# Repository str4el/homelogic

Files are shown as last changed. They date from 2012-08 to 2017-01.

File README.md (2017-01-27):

Homelogic
---------

Die Homelogic ist eine dezentral arbeitende __SPS Steuerung__, die für den Hausgebrauch gedacht ist. Es gibt verschiedene Hardware die mit der selben Firmware laufen. Die meisten sind für den direktem betrieb am Netz ausgelegt und haben mehrere digitale Ein- und Ausgänge.

Das Projekt besteht aus den Plänen für die _Hardware_, der _Firmware_ darin, einer _Bibliothek_ und einen darauf aufbauendem _Steuerprogramm_.

Die Steuerung ist SPS typisch frei programmierbar, als Sprache kommt dafür eine Variante von _Anweisungsliste_ zum Einsatz.

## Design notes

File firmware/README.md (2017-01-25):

Firmware
========

Erstellen
---------

`make menuconfig` zeigt ein Auswahlmenü um die Firmwareoptionen
auszuwählen. Bei der ersten Ausführung werden die Standardeinstellungen
geladen. Es wird nun die Ausbaustufe ausgewählt.

Die Firmware wird mit `make` erstellt

`make distclean` löscht alle erzeugten Dateien inklusive der
Konfiguration.

Erstinstallation
----------------

Bei der USB Variante ist der Bootloader von Atmel vorinstalliert und
die Sicherheitsbits sind gesetzt, was ein Überschreiben durch __avrdude__
verhindert.
Da die Fuses für die Funktion der Firmware geändert werden müssen,
muss vorher ein _chiperase_ durchgeführt werden. Danach können mit
`make fuses` die Fuses richtig eingestellt werden.

Ist der __BOOTLOADER_SUPPORT__ aktiviert, muss der mitgelieferte
Bootloader von Atmel mit __avrdude__ installiert werden.

`make program` überträgt die Firmware.

Bei allen anderen Varianten reicht ein `make fuses program` aus.

Update
------

Um die Firmware von einer älteren Version zu aktualisieren reicht
ein `make program` aus.

Beispiel
--------

#### Erstinstallation USB-CPU mit Vollausstattung und Verwendung von AVR ISP MK2

`make distclean` wenn das Verzeichnis nicht sauber war.

`make menuconfig`

Nach der Auswahl `(CPU_USB) Target Hardware` müssen noch foglende optionen
gesetzt werden.

- `[*] I2C BUS --> [*] Real Time Clock`
- `[*] USB Support`
- `[*] Bootloader Support`

`make` erstellt die Firmware

Den Bootloader mit AVR ISP MK2 übertragen. Dabei wird ein _chiperase_ Ausgelöst.  
`avrdude -c avrispmkii -P usb -p at90usb1287 -U flash:w:at90usb128-bl-usb-1_0_1.hex:i`  
Der Bootloader ist nicht im Projekt enthalten kann aber von [Atmel](http://www.atmel.com/Images/megaUSB_DFU_Bootloaders.zip) bezogen werden.

`make fuses` um die setzt die Fusebits.

`make program` flasht die Firmware über den Bootloader per USB.

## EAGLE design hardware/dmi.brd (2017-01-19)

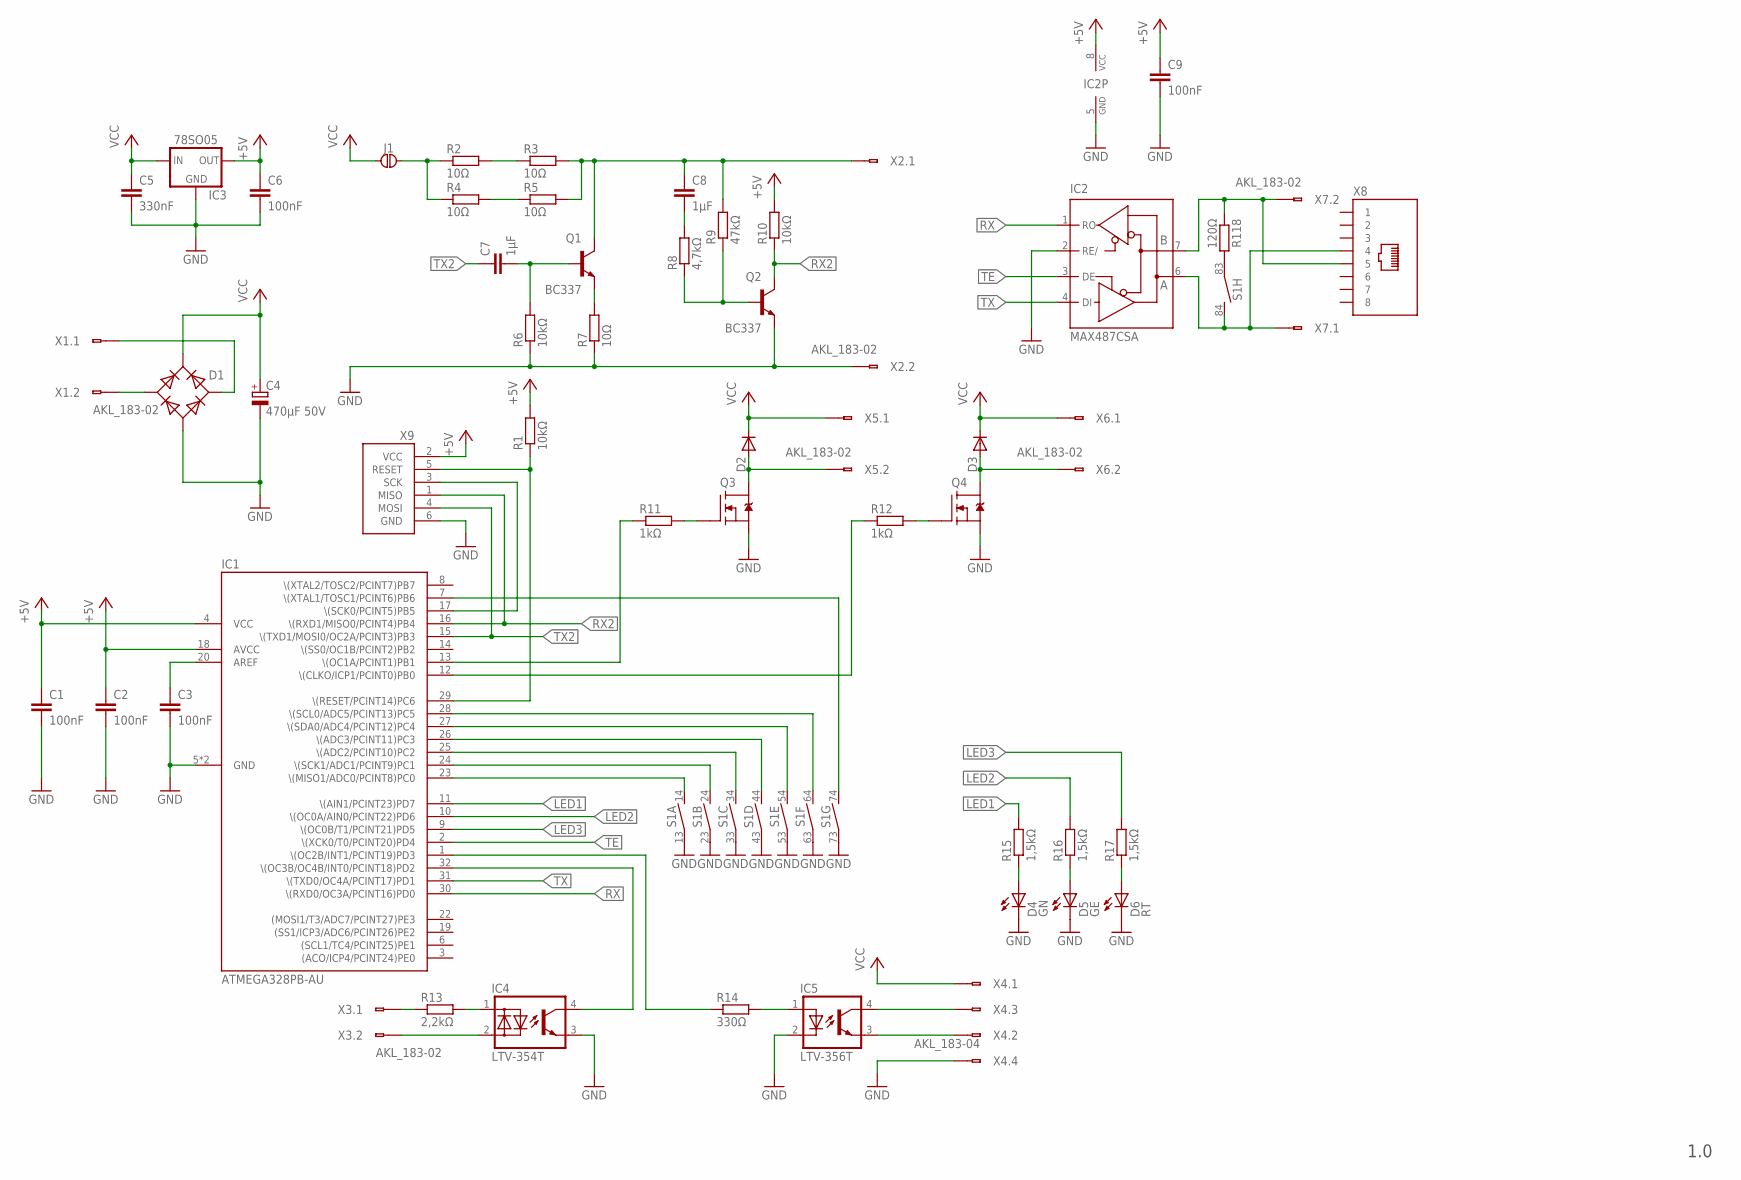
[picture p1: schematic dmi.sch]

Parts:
C1, C2, C3, C9: 100nF; CHIP_0603
C4: 470μF 50V; E5-13
C5: 330nF; CHIP_0805
C6: 100nF; CHIP_0805
C7, C8: 1μF; CHIP_1206
D1: GLEICHRICHTER-SDIP; SDIP04_508
D2, D3: DIODE-SOD123; SOD123
D4: GN; CHIP_0805
D5: GE; CHIP_0805
D6: RT; CHIP_0805
IC1: ATMEGA328PB-AU; QFP32_08
IC2: MAX487CSA; SOP08_127
IC3: 78SO05; SOP08_127
IC4: LTV-354T; SOP04_254
IC5: LTV-356T; SOP04_254
J1: JUMPER; JUMPER2
Q1, Q2: BC337; SOT23
Q3, Q4: N-MOS-SOT23-GSD; SOT23
R1, R6, R10: 10kΩ; CHIP_0603
R2, R3, R4, R5, R7: 10Ω; CHIP_1206
R8: 4,7kΩ; CHIP_0603
R9: 47kΩ; CHIP_0603
R11, R12: 1kΩ; CHIP_0603
R13: 2,2kΩ; CHIP_0603
R14: 330Ω; CHIP_0603
R15, R16, R17: 1,5kΩ; CHIP_0603
R118: 120Ω; CHIP_0805
S1: DP08D; DIP08_SMD
X1, X2, X3, X5, X6, X7: AKL_183-02
X4: AKL_183-04
X8: 8P8C; C-BMJ-0102
X9: ISP-AVR6; ML6

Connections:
+5V: C1.1, C2.1, C6.1, C9.1, IC1.4 (VCC), IC1.18 (AVCC), IC2.8 (VCC), IC3.1 (OUT), R1.2, R10.2, X9.2 (VCC)
GND: C1.2, C2.2, C3.2, C4.-, C5.2, C6.2, C9.2, D1.2 (-), D4.2 (C), D5.2 (C), D6.2 (C), IC1.5 (GND), IC1.21 (GND), IC2.2 (RE/), IC2.5 (GND), IC3.2 (GND), IC3.3 (GND), IC3.6 (GND), IC3.7 (GND), IC4.3 (E), IC5.2 (K), Q2.2 (E), Q3.2 (S), Q4.2 (S), R6.1, R7.1, S1.13 (3), S1.23 (3), S1.33 (3), S1.43 (3), S1.53 (3), S1.63 (3), S1.73 (3), X2.2, X4.4, X9.6 (GND)
LED1: IC1.11 (\(AIN1/PCINT23)PD7), R15.2
LED2: IC1.10 (\(OC0A/AIN0/PCINT22)PD6), R16.2
LED3: IC1.9 (\(OC0B/T1/PCINT21)PD5), R17.2
unnamed: IC1.32 (\(OC3B/OC4B/INT0/PCINT18)PD2), IC4.4 (C)
unnamed: IC4.2 (K), X3.2
unnamed: IC2.6 (A), S1.84 (4), X7.1, X8.P$4 (4)
unnamed: IC1.29 (\(RESET/PCINT14)PC6), R1.1, X9.5 (RESET)
unnamed: IC1.13 (\(OC1A/PCINT1)PB1), R11.1
unnamed: Q3.1 (G), R11.2
unnamed: D2.A, Q3.3 (D), X5.2
unnamed: IC5.3 (E), X4.2
unnamed: IC5.4 (C), X4.3
unnamed: IC1.1 (\(OC2B/INT1/PCINT19)PD3), R14.1
unnamed: IC5.1 (A), R14.2
unnamed: J1.P$2, R2.1, R4.1
unnamed: R2.2, R3.1
unnamed: R13.1, X3.1
unnamed: IC4.1 (A), R13.2
unnamed: Q1.2 (E), R7.2
unnamed: C7.2, Q1.1 (B), R6.2
unnamed: Q2.1 (B), R8.1, R9.1
unnamed: C8.2, R8.2
unnamed: D1.4 (AC2), X1.1
unnamed: C8.1, Q1.3 (C), R3.2, R5.2, R9.2, X2.1
unnamed: D1.3 (AC1), X1.2
unnamed: R4.2, R5.1
unnamed: Q4.1 (G), R12.2
unnamed: D3.A, Q4.3 (D), X6.2
unnamed: IC1.12 (\(CLKO/ICP1/PCINT0)PB0), R12.1
unnamed: IC2.7 (B), R118.1, X7.2, X8.P$5 (5)
unnamed: IC1.23 (\(MISO1/ADC0/PCINT8)PC0), S1.14 (4)
unnamed: IC1.24 (\(SCK1/ADC1/PCINT9)PC1), S1.24 (4)
unnamed: IC1.25 (\(ADC2/PCINT10)PC2), S1.34 (4)
unnamed: IC1.26 (\(ADC3/PCINT11)PC3), S1.44 (4)
unnamed: IC1.27 (\(SDA0/ADC4/PCINT12)PC4), S1.54 (4)
unnamed: R118.2, S1.83 (3)
unnamed: IC1.28 (\(SCL0/ADC5/PCINT13)PC5), S1.64 (4)
unnamed: IC1.7 (\(XTAL1/TOSC1/PCINT6)PB6), S1.74 (4)
unnamed: D6.1 (A), R17.1
unnamed: IC1.17 (\(SCK0/PCINT5)PB5), X9.3 (SCK)
unnamed: C3.1, IC1.20 (AREF)
unnamed: D4.1 (A), R15.1
unnamed: D5.1 (A), R16.1
RX: IC1.30 (\(RXD0/OC3A/PCINT16)PD0), IC2.1 (RO)
RX2: IC1.16 (\(RXD1/MISO0/PCINT4)PB4), Q2.3 (C), R10.1, X9.1 (MISO)
TE: IC1.2 (\(XCK0/T0/PCINT20)PD4), IC2.3 (DE)
TX: IC1.31 (\(TXD0/OC4A/PCINT17)PD1), IC2.4 (DI)
TX2: C7.1, IC1.15 (\(TXD1/MOSI0/OC2A/PCINT3)PB3), X9.4 (MOSI)
VCC: C4.+, C5.1, D1.1 (+), D2.K, D3.K, IC3.8 (IN), J1.P$1, X4.1, X5.1, X6.1

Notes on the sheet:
1.0

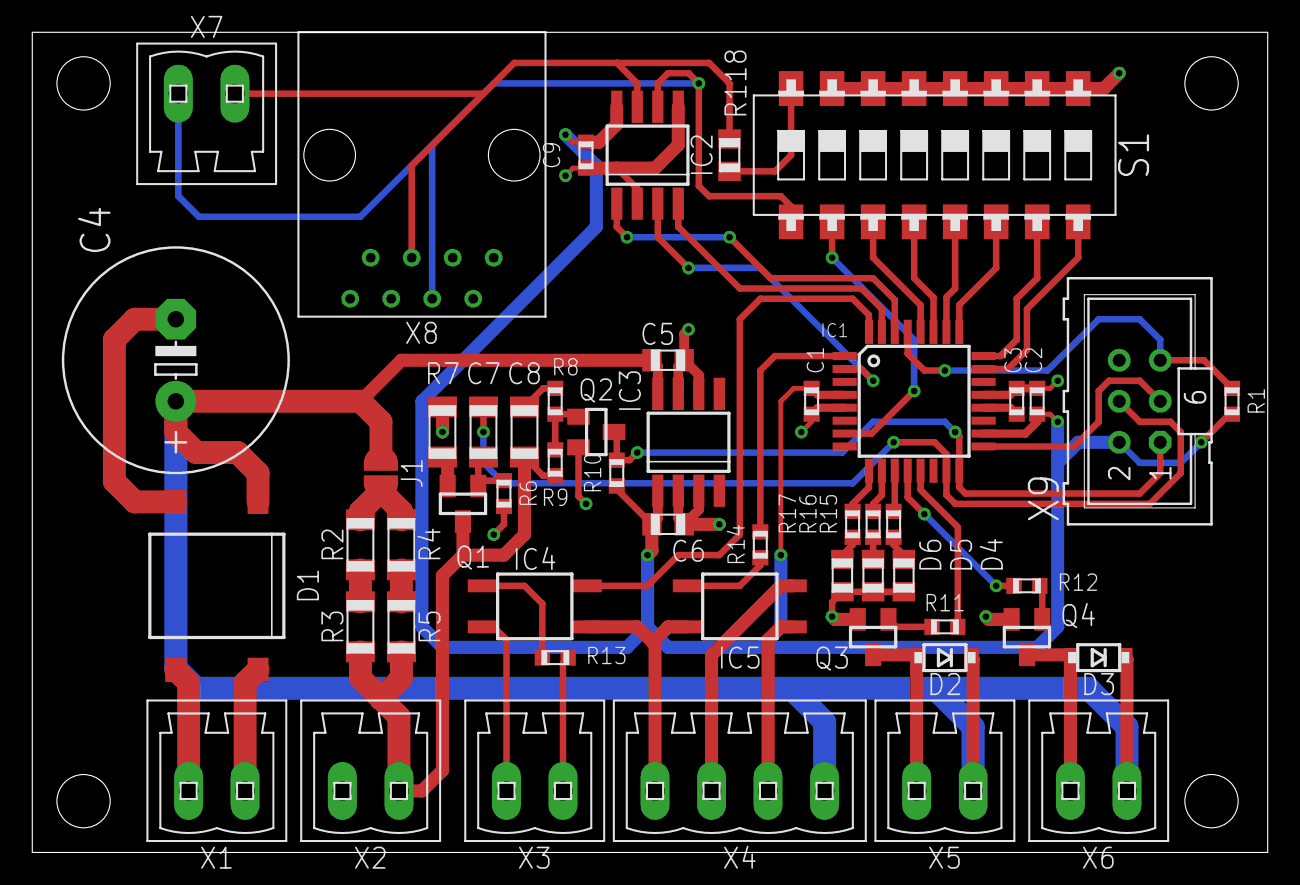
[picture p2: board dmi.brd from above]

Board: 2 copper layers, 76.5 x 50.8 mm, 53 parts (0 on the bottom side), 51 nets.

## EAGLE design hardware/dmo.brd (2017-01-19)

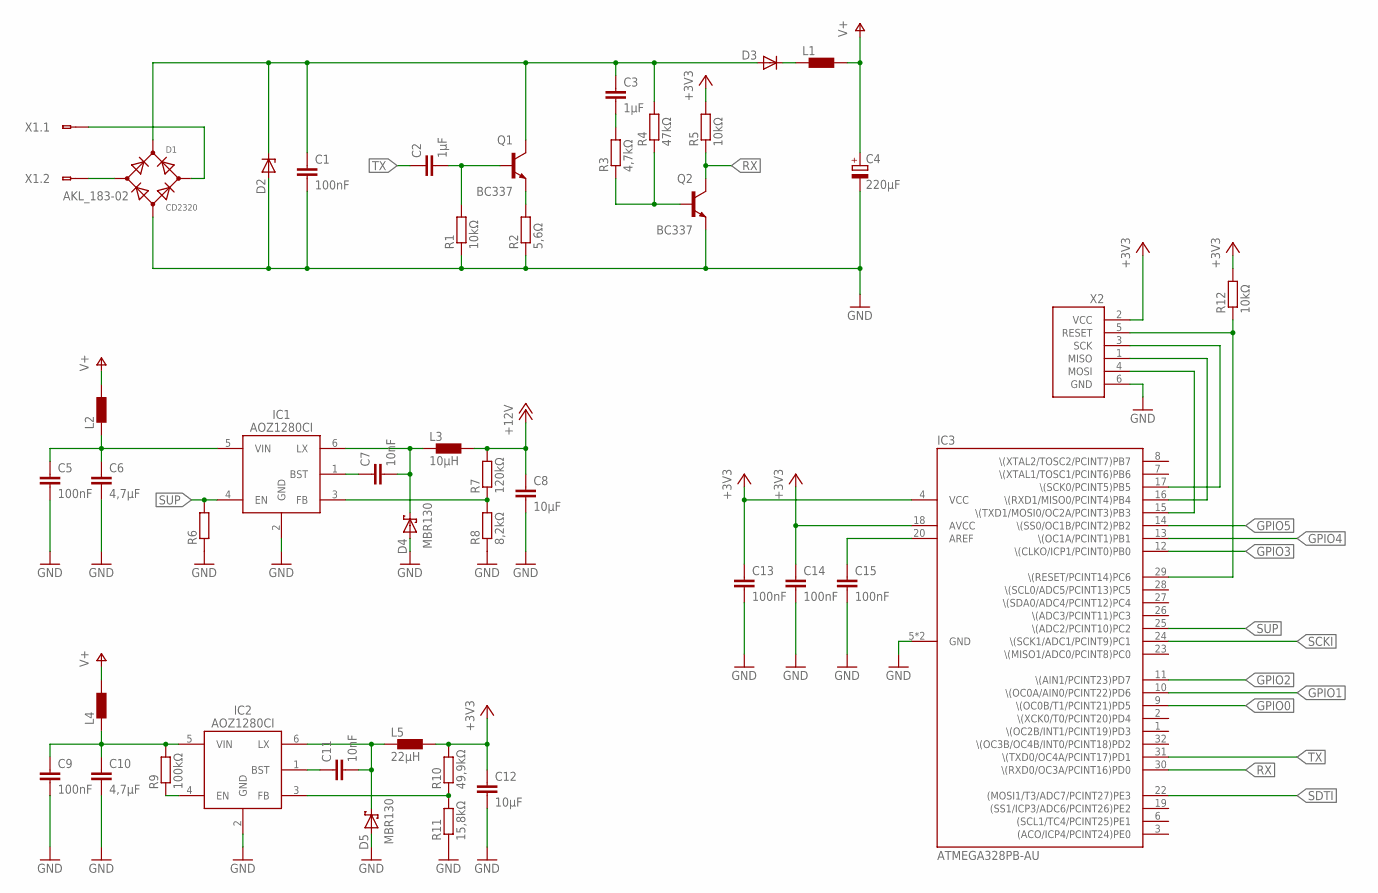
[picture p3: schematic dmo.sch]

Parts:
C1: 100nF; CHIP_1206
C2, C3: 1μF; CHIP_1206
C4: 220μF; E5-13
C5, C9: 100nF; CHIP_0805
C6, C10: 4,7μF; CHIP_1206
C7, C11: 10nF; CHIP_0603
C8, C12: 10μF; CHIP_1206
C13, C14, C15: 100nF; CHIP_0603
D1: CD2320; 2320
D2: Z-DIODE-SOD123; SOD123
D3: DIODE-SOD123; SOD123
D4, D5: MBR130; SOD123
IC1, IC2: AOZ1280CI; SOT23-6_095
IC3: ATMEGA328PB-AU; QFP32_08
L1, L2, L4: L_0805; CHIP_0805
L3: 10μH; CHIP_1210
L5: 22μH; CHIP_0805
Q1, Q2: BC337; SOT23
R1, R5, R12: 10kΩ; CHIP_0603
R2: 5,6Ω; CHIP_1206
R3: 4,7kΩ; CHIP_0603
R4: 47kΩ; CHIP_0603
R6: R_0603; CHIP_0603
R7: 120kΩ; CHIP_0603
R8: 8,2kΩ; CHIP_0603
R9: 100kΩ; CHIP_0603
R10: 49,9kΩ; CHIP_0603
R11: 15,8kΩ; CHIP_0603
X1: AKL_183-02
X2: ISP-AVR6; ML6

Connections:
+3V3: C12.1, C13.1, C14.1, IC3.4 (VCC), IC3.18 (AVCC), L5.1, R5.2, R10.2, R12.2, X2.2 (VCC)
+12V: C8.1, L3.1, R7.2
GND: C1.2, C4.-, C5.2, C6.2, C8.2, C9.2, C10.2, C12.2, C13.2, C14.2, C15.2, D1.-, D2.A, D4.A, D5.A, IC1.2 (GND), IC2.2 (GND), IC3.5 (GND), IC3.21 (GND), Q2.2 (E), R1.1, R2.1, R6.1, R8.1, R11.1, X2.6 (GND)
GPIO0: IC3.9 (\(OC0B/T1/PCINT21)PD5)
GPIO1: IC3.10 (\(OC0A/AIN0/PCINT22)PD6)
GPIO2: IC3.11 (\(AIN1/PCINT23)PD7)
GPIO3: IC3.12 (\(CLKO/ICP1/PCINT0)PB0)
GPIO4: IC3.13 (\(OC1A/PCINT1)PB1)
GPIO5: IC3.14 (\(SS0/OC1B/PCINT2)PB2)
unnamed: IC3.16 (\(RXD1/MISO0/PCINT4)PB4), X2.1 (MISO)
unnamed: IC3.15 (\(TXD1/MOSI0/OC2A/PCINT3)PB3), X2.4 (MOSI)
unnamed: D3.K, L1.2
unnamed: IC3.17 (\(SCK0/PCINT5)PB5), X2.3 (SCK)
unnamed: IC3.29 (\(RESET/PCINT14)PC6), R12.1, X2.5 (RESET)
unnamed: IC2.4 (EN), R9.1
unnamed: C11.1, IC2.1 (BST)
unnamed: C11.2, D5.K, IC2.6 (LX), L5.2
unnamed: IC2.3 (FB), R10.1, R11.2
unnamed: C9.1, C10.1, IC2.5 (VIN), L4.2, R9.2
unnamed: C7.1, IC1.1 (BST)
unnamed: C7.2, D4.K, IC1.6 (LX), L3.2
unnamed: IC1.3 (FB), R7.1, R8.2
unnamed: C5.1, C6.1, IC1.5 (VIN), L2.2
unnamed: C15.1, IC3.20 (AREF)
unnamed: Q1.2 (E), R2.2
unnamed: C2.2, Q1.1 (B), R1.2
unnamed: Q2.1 (B), R3.1, R4.1
unnamed: C3.2, R3.2
unnamed: D1.AC2, X1.1
unnamed: D1.AC1, X1.2
RX: IC3.30 (\(RXD0/OC3A/PCINT16)PD0), Q2.3 (C), R5.1
SCKI: IC3.24 (\(SCK1/ADC1/PCINT9)PC1)
SDTI: IC3.22 ((MOSI1/T3/ADC7/PCINT27)PE3)
SUP: IC1.4 (EN), IC3.25 (\(ADC2/PCINT10)PC2), R6.2
TX: C2.1, IC3.31 (\(TXD0/OC4A/PCINT17)PD1)
V+: C4.+, L1.1, L2.1, L4.1
VCC: C1.1, C3.1, D1.+, D2.K, D3.A, Q1.3 (C), R4.2

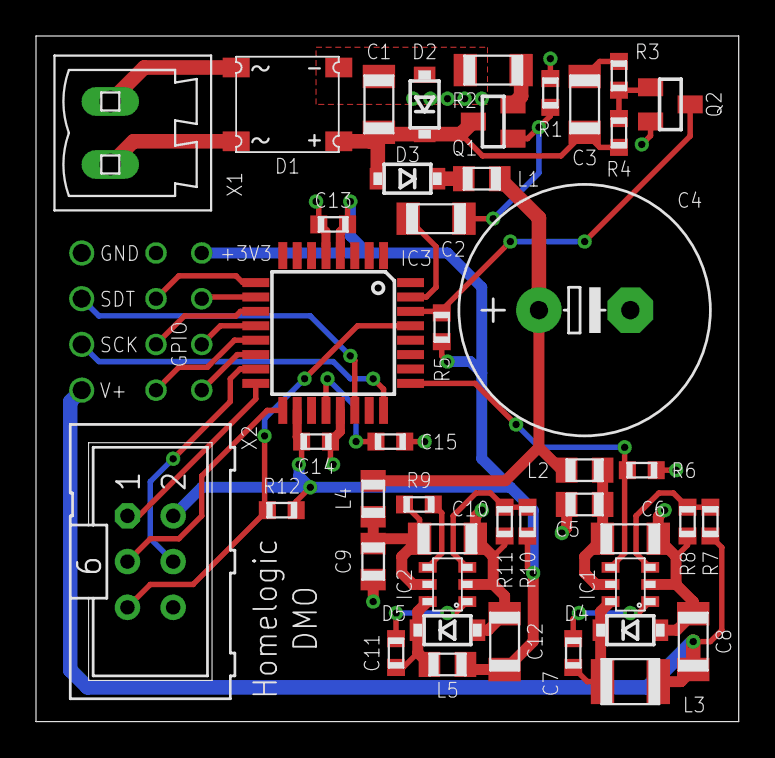
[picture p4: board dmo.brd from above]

Board: 2 copper layers, 39.0 x 38.1 mm, 44 parts (0 on the bottom side), 29 nets.

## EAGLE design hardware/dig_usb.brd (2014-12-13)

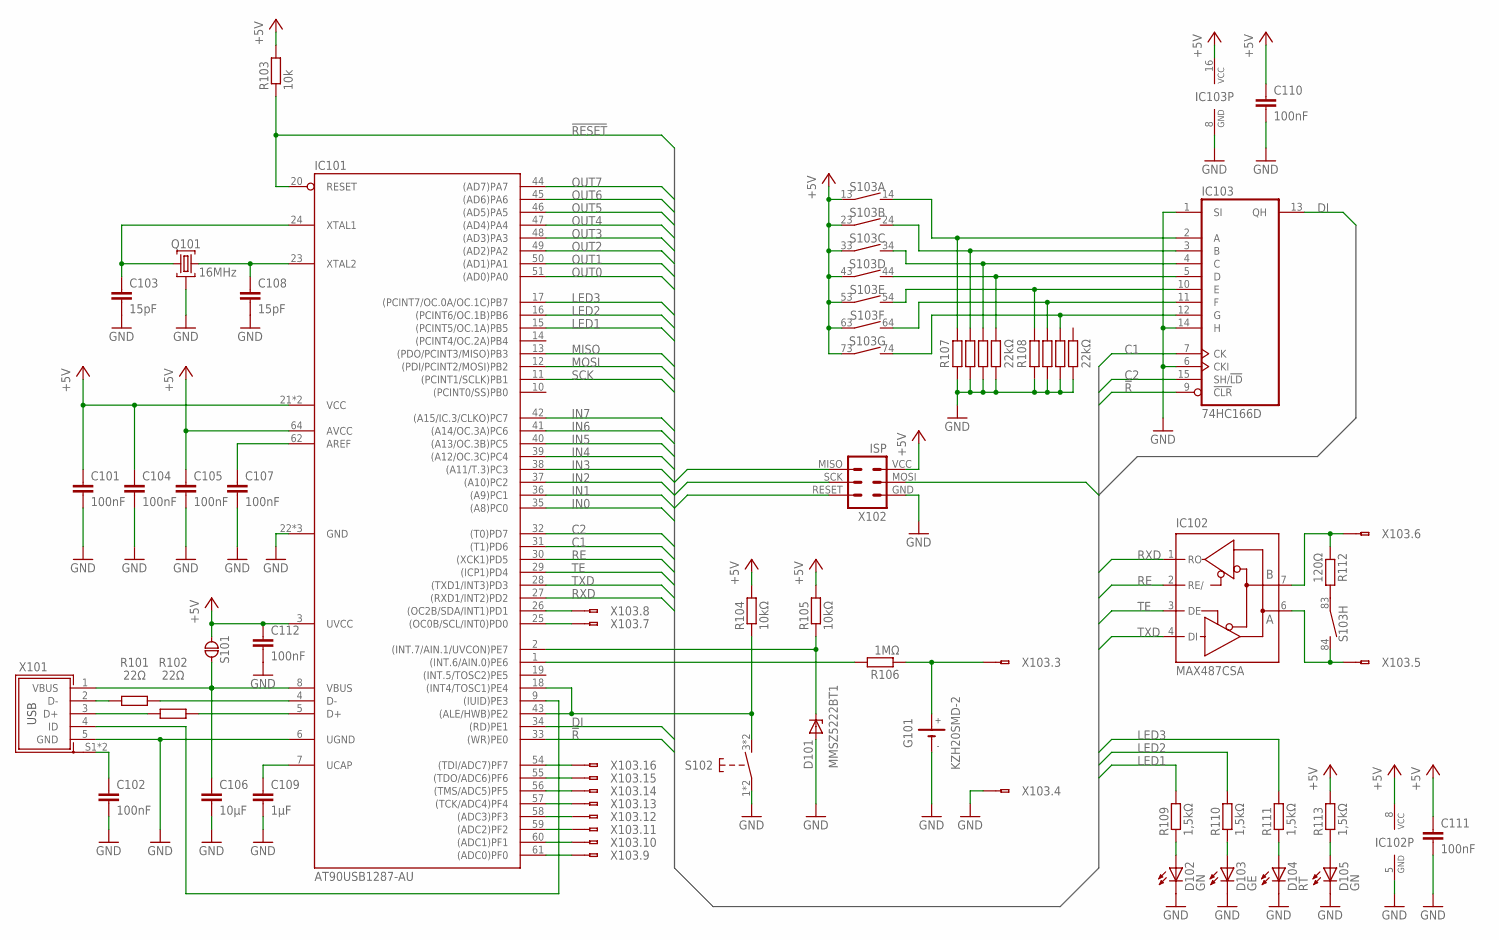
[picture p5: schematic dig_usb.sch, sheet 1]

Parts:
C101, C104, C105, C107, C110, C111, C112: 100nF; CHIP_0603
C102: 100nF; CHIP_0805
C103, C108: 15pF; CHIP_0805
C106: 10μF; CHIP_0805
C109: 1μF; CHIP_0805
D101: MMSZ5222BT1; SOD123
D102, D105: GN; CHIP_0805
D103: GE; CHIP_0805
D104: RT; CHIP_0805
G101: KZH20SMD-2; KHZ20SMD-2
IC101: AT90USB1287-AU; QFP64_08
IC102: MAX487CSA; SOP08_127
IC103: 74HC166D; SOP16_127
Q101: 16MHz; X22
R101, R102: 22Ω; CHIP_0805
R103: 10k; CHIP_0805
R104, R105: 10kΩ; CHIP_0805
R106: 1MΩ; CHIP_0805
R107, R108: 22kΩ; 1206
R109, R110, R111, R113: 1,5kΩ; CHIP_0805
R112: 120Ω; CHIP_0805
S101: JUMPER; JUMPER2
S102: KURZHUBS1; SCHURTER1301
S103: DP08D; DIP08_SMD
X101: USB-MINI-V; WE651005136421
X102: ISP; ML6
X103: WS34V

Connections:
!R: IC101.33 ((WR)PE0), IC103.9 (!CLR)
!RESET: IC101.20 (RESET), R103.1, X102.RESET
+5V: C101.1, C104.1, C105.1, C110.1, C111.1, C112.1, IC101.3 (UVCC), IC101.21 (VCC), IC101.52 (VCC), IC101.64 (AVCC), IC102.8 (VCC), IC103.16 (VCC), R103.2, R104.2, R105.2, R113.2, S101.P$1, S103.13 (3), S103.23 (3), S103.33 (3), S103.43 (3), S103.53 (3), S103.63 (3), S103.73 (3), X102.VCC; also elsewhere on the board
C1: IC101.31 ((T1)PD6), IC103.7 (CK)
C2: IC101.32 ((T0)PD7), IC103.15 (SH/!LD)
DI: IC101.34 ((RD)PE1), IC103.13 (QH)
GND: C101.2, C102.2, C103.2, C104.2, C105.2, C106.2, C107.2, C108.2, C109.2, C110.2, C111.2, C112.2, D101.A, D102.2 (C), D103.2 (C), D104.2 (C), D105.2 (C), G101.-, IC101.6 (UGND), IC101.22 (GND), IC101.53 (GND), IC101.63 (GND), IC102.5 (GND), IC103.1 (SI), IC103.6 (CKI), IC103.8 (GND), IC103.14 (H), Q101.2 (G), Q101.4 (G), R107.1A (1), R107.2A (3), R107.3A (5), R107.4A (7), R108.1A (1), R108.2A (3), R108.3A (5), R108.4A (7), S102.1, S102.2, X101.5 (GND), X102.GND, X103.4; also elsewhere on the board
IN0: IC101.35 ((A8)PC0); also elsewhere on the board
IN1: IC101.36 ((A9)PC1); also elsewhere on the board
IN2: IC101.37 ((A10)PC2); also elsewhere on the board
IN3: IC101.38 ((A11/T.3)PC3); also elsewhere on the board
IN4: IC101.39 ((A12/OC.3C)PC4); also elsewhere on the board
IN5: IC101.40 ((A13/OC.3B)PC5); also elsewhere on the board
IN6: IC101.41 ((A14/OC.3A)PC6); also elsewhere on the board
IN7: IC101.42 ((A15/IC.3/CLKO)PC7); also elsewhere on the board
LED1: IC101.15 ((PCINT5/OC.1A)PB5), R109.2
LED2: IC101.16 ((PCINT6/OC.1B)PB6), R110.2
LED3: IC101.17 ((PCINT7/OC.0A/OC.1C)PB7), R111.2
MISO: IC101.13 ((PDO/PCINT3/MISO)PB3), X102.MISO
MOSI: IC101.12 ((PDI/PCINT2/MOSI)PB2), X102.MOSI
unnamed: D104.1 (A), R111.1
unnamed: C107.1, IC101.62 (AREF)
unnamed: IC102.6 (A), S103.84 (4), X103.5
unnamed: IC101.1 ((INT.6/AIN.0)PE6), R106.2
unnamed: IC102.7 (B), R112.1, X103.6
unnamed: IC103.2 (A), R107.1B (2), S103.14 (4)
unnamed: IC103.3 (B), R107.2B (4), S103.24 (4)
unnamed: IC103.4 (C), R107.3B (6), S103.34 (4)
unnamed: IC103.5 (D), R107.4B (8), S103.44 (4)
unnamed: IC103.10 (E), R108.1B (2), S103.54 (4)
unnamed: IC103.11 (F), R108.2B (4), S103.64 (4)
unnamed: IC103.12 (G), R108.3B (6), S103.74 (4)
unnamed: R112.2, S103.83 (3)
unnamed: D105.1 (A), R113.1
unnamed: D102.1 (A), R109.1
unnamed: D103.1 (A), R110.1
unnamed: C109.1, IC101.7 (UCAP)
unnamed: R102.1, X101.3 (D+)
unnamed: IC101.5 (D+), R102.2
unnamed: R101.1, X101.2 (D-)
unnamed: IC101.4 (D-), R101.2
unnamed: IC101.9 ((IUID)PE3), X101.4 (ID)
unnamed: C106.1, IC101.8 (VBUS), S101.P$2, X101.1 (VBUS)
unnamed: C108.1, IC101.23 (XTAL2), Q101.3 (2)
unnamed: C103.1, IC101.24 (XTAL1), Q101.1
unnamed: D101.K, IC101.2 ((INT.7/AIN.1/UVCON)PE7), R105.1
unnamed: IC101.61 ((ADC0)PF0), X103.9
unnamed: IC101.60 ((ADC1)PF1), X103.10
unnamed: IC101.59 ((ADC2)PF2), X103.11
unnamed: IC101.58 ((ADC3)PF3), X103.12
unnamed: IC101.57 ((TCK/ADC4)PF4), X103.13
unnamed: IC101.56 ((TMS/ADC5)PF5), X103.14
unnamed: IC101.55 ((TDO/ADC6)PF6), X103.15
unnamed: IC101.54 ((TDI/ADC7)PF7), X103.16
unnamed: G101.+, R106.1, X103.3
unnamed: IC101.25 ((OC0B/SCL/INT0)PD0), X103.7
unnamed: IC101.26 ((OC2B/SDA/INT1)PD1), X103.8
unnamed: IC101.18 ((INT4/TOSC1)PE4), IC101.43 ((ALE/HWB)PE2), R104.1, S102.3 (S), S102.4 (S)
OUT0: IC101.51 ((AD0)PA0); also elsewhere on the board
OUT1: IC101.50 ((AD1)PA1); also elsewhere on the board
OUT2: IC101.49 ((AD2)PA2); also elsewhere on the board
OUT3: IC101.48 ((AD3)PA3); also elsewhere on the board
OUT4: IC101.47 ((AD4)PA4); also elsewhere on the board
OUT5: IC101.46 ((AD5)PA5); also elsewhere on the board
OUT6: IC101.45 ((AD6)PA6); also elsewhere on the board
OUT7: IC101.44 ((AD7)PA7); also elsewhere on the board
RE: IC101.30 ((XCK1)PD5), IC102.2 (RE/)
RXD: IC101.27 ((RXD1/INT2)PD2), IC102.1 (RO)
SCK: IC101.11 ((PCINT1/SCLK)PB1), X102.SCK
TE: IC101.29 ((ICP1)PD4), IC102.3 (DE)
TXD: IC101.28 ((TXD1/INT3)PD3), IC102.4 (DI)
USHIELD: C102.1, X101.S1 (SHIELD), X101.S2 (SHIELD)

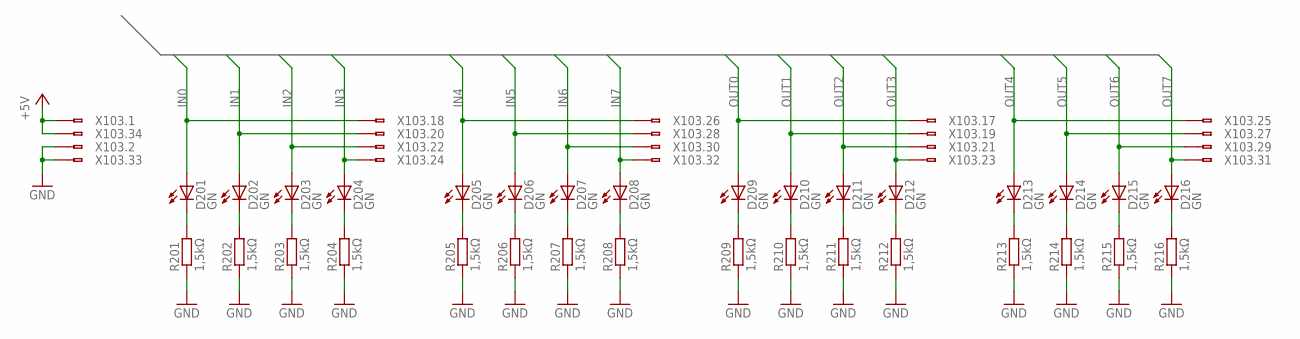
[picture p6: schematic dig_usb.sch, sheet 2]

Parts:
D201, D202, D203, D204, D205, D206, D207, D208, D209, D210, D211, D212, D213, D214, D215, D216: GN; CHIP_0805
R201, R202, R203, R204, R205, R206, R207, R208, R209, R210, R211, R212, R213, R214, R215, R216: 1,5kΩ; CHIP_0805
X103: WS34V

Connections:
+5V: X103.1, X103.34; also elsewhere on the board
GND: R201.1, R202.1, R203.1, R204.1, R205.1, R206.1, R207.1, R208.1, R209.1, R210.1, R211.1, R212.1, R213.1, R214.1, R215.1, R216.1, X103.2, X103.33; also elsewhere on the board
IN0: D201.1 (A), X103.18; also elsewhere on the board
IN1: D202.1 (A), X103.20; also elsewhere on the board
IN2: D203.1 (A), X103.22; also elsewhere on the board
IN3: D204.1 (A), X103.24; also elsewhere on the board
IN4: D205.1 (A), X103.26; also elsewhere on the board
IN5: D206.1 (A), X103.28; also elsewhere on the board
IN6: D207.1 (A), X103.30; also elsewhere on the board
IN7: D208.1 (A), X103.32; also elsewhere on the board
unnamed: D201.2 (C), R201.2
unnamed: D202.2 (C), R202.2
unnamed: D203.2 (C), R203.2
unnamed: D204.2 (C), R204.2
unnamed: D205.2 (C), R205.2
unnamed: D206.2 (C), R206.2
unnamed: D207.2 (C), R207.2
unnamed: D208.2 (C), R208.2
unnamed: D209.2 (C), R209.2
unnamed: D210.2 (C), R210.2
unnamed: D211.2 (C), R211.2
unnamed: D212.2 (C), R212.2
unnamed: D213.2 (C), R213.2
unnamed: D214.2 (C), R214.2
unnamed: D215.2 (C), R215.2
unnamed: D216.2 (C), R216.2
OUT0: D209.1 (A), X103.17; also elsewhere on the board
OUT1: D210.1 (A), X103.19; also elsewhere on the board
OUT2: D211.1 (A), X103.21; also elsewhere on the board
OUT3: D212.1 (A), X103.23; also elsewhere on the board
OUT4: D213.1 (A), X103.25; also elsewhere on the board
OUT5: D214.1 (A), X103.27; also elsewhere on the board
OUT6: D215.1 (A), X103.29; also elsewhere on the board
OUT7: D216.1 (A), X103.31; also elsewhere on the board

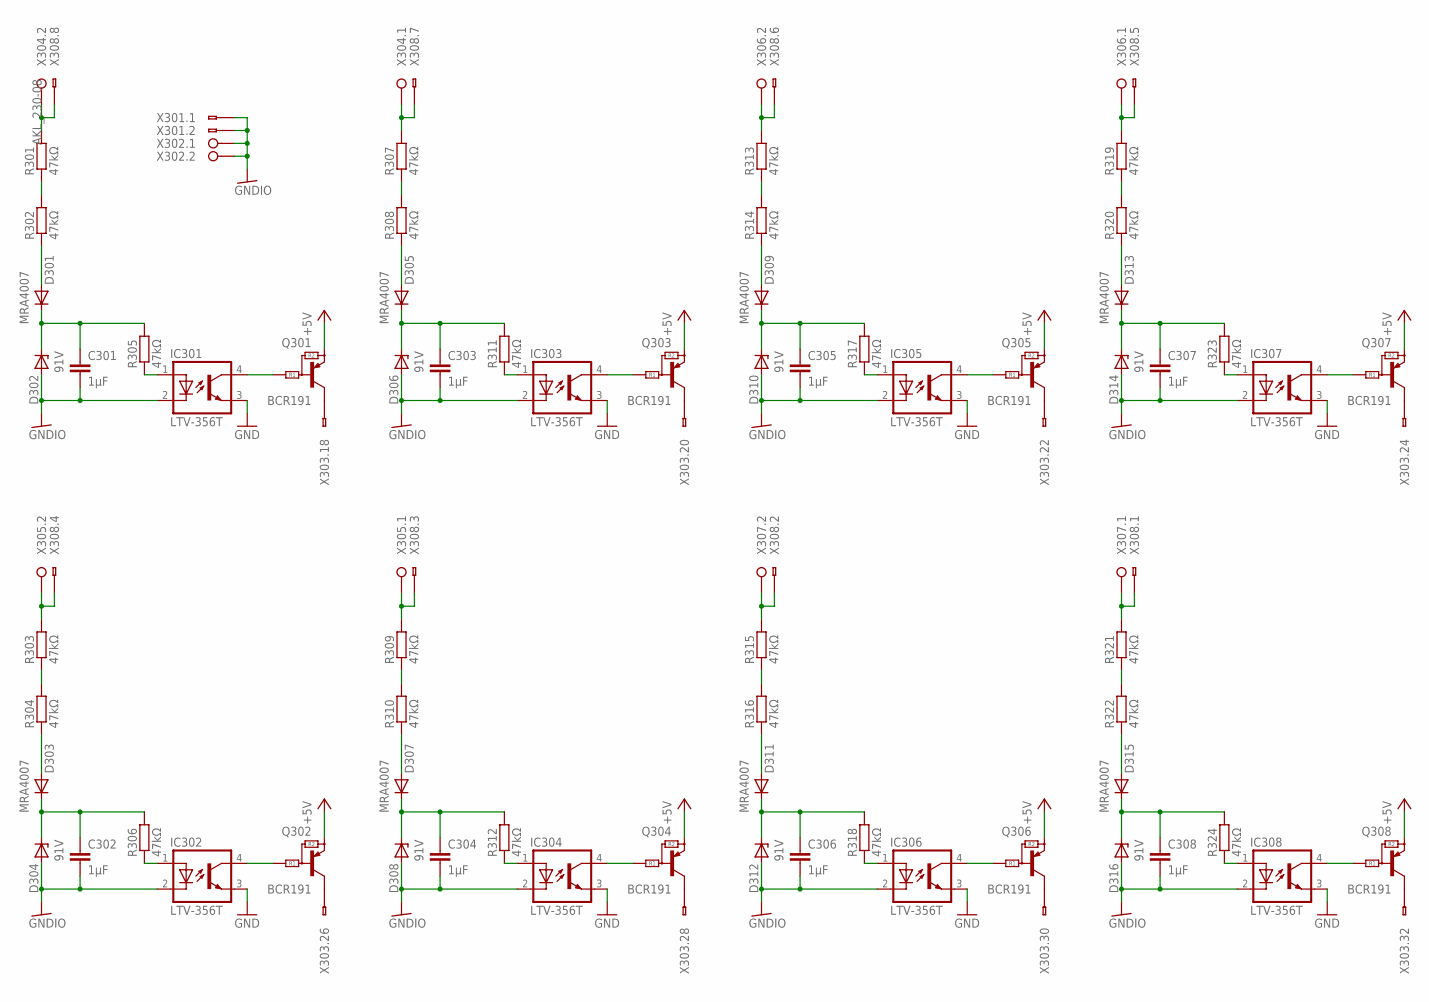
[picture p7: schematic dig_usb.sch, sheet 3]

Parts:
C301, C302, C303, C304, C305, C306, C307, C308: 1μF; CHIP_1206
D301, D303, D305, D307, D309, D311, D313, D315: MRA4007; DO214AC
D302, D304, D306, D308, D310, D312, D314, D316: 91V; SOD123
IC301, IC302, IC303, IC304, IC305, IC306, IC307, IC308: LTV-356T; SOP04_254
Q301, Q302, Q303, Q304, Q305, Q306, Q307, Q308: BCR191; SOT23
R301, R302, R303, R304, R305, R306, R307, R308, R309, R310, R311, R312, R313, R314, R315, R316, R317, R318, R319, R320, R321, R322, R323, R324: 47kΩ; CHIP_1206
X301: AKL_230-02
X302, X304, X305, X306, X307: RIA-73-02
X303: WS34V
X308: AKL_230-08

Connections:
+5V: Q301.2 (E), Q302.2 (E), Q303.2 (E), Q304.2 (E), Q305.2 (E), Q306.2 (E), Q307.2 (E), Q308.2 (E); also elsewhere on the board
GND: IC301.3 (E), IC302.3 (E), IC303.3 (E), IC304.3 (E), IC305.3 (E), IC306.3 (E), IC307.3 (E), IC308.3 (E); also elsewhere on the board
GNDIO: C301.2, C302.2, C303.2, C304.2, C305.2, C306.2, C307.2, C308.2, D302.A, D304.A, D306.A, D308.A, D310.A, D312.A, D314.A, D316.A, IC301.2 (K), IC302.2 (K), IC303.2 (K), IC304.2 (K), IC305.2 (K), IC306.2 (K), IC307.2 (K), IC308.2 (K), X301.P$1, X301.P$2, X302.1, X302.2; also elsewhere on the board
unnamed: R301.1, R302.2
unnamed: D301.A, R302.1
unnamed: C301.1, D301.K, D302.K, R305.2
unnamed: IC301.1 (A), R305.1
unnamed: D305.A, R308.1
unnamed: C303.1, D305.K, D306.K, R311.2
unnamed: IC303.1 (A), R311.1
unnamed: D309.A, R314.1
unnamed: C305.1, D309.K, D310.K, R317.2
unnamed: IC305.1 (A), R317.1
unnamed: D313.A, R320.1
unnamed: C307.1, D313.K, D314.K, R323.2
unnamed: R307.1, R308.2
unnamed: R313.1, R314.2
unnamed: IC307.1 (A), R323.1
unnamed: D303.A, R304.1
unnamed: C302.1, D303.K, D304.K, R306.2
unnamed: IC302.1 (A), R306.1
unnamed: D307.A, R310.1
unnamed: C304.1, D307.K, D308.K, R312.2
unnamed: R319.1, R320.2
unnamed: R307.2, X304.1, X308.P$7
unnamed: R301.2, X304.2, X308.P$8
unnamed: R319.2, X306.1, X308.P$5
unnamed: R313.2, X306.2, X308.P$6
unnamed: R303.1, R304.2
unnamed: R309.1, R310.2
unnamed: IC307.4 (C), Q307.1 (B)
unnamed: R315.1, R316.2
unnamed: R321.1, R322.2
unnamed: IC304.1 (A), R312.1
unnamed: R303.2, X305.2, X308.P$4
unnamed: D311.A, R316.1
unnamed: R309.2, X305.1, X308.P$3
unnamed: R321.2, X307.1, X308.P$1
unnamed: R315.2, X307.2, X308.P$2
unnamed: C306.1, D311.K, D312.K, R318.2
unnamed: IC306.1 (A), R318.1
unnamed: IC305.4 (C), Q305.1 (B)
unnamed: D315.A, R322.1
unnamed: IC303.4 (C), Q303.1 (B)
unnamed: IC301.4 (C), Q301.1 (B)
unnamed: C308.1, D315.K, D316.K, R324.2
unnamed: IC302.4 (C), Q302.1 (B)
unnamed: IC304.4 (C), Q304.1 (B)
unnamed: IC306.4 (C), Q306.1 (B)
unnamed: IC308.4 (C), Q308.1 (B)
unnamed: IC308.1 (A), R324.1
unnamed: Q301.3 (C), X303.18
unnamed: Q303.3 (C), X303.20
unnamed: Q305.3 (C), X303.22
unnamed: Q307.3 (C), X303.24
unnamed: Q302.3 (C), X303.26
unnamed: Q304.3 (C), X303.28
unnamed: Q306.3 (C), X303.30
unnamed: Q308.3 (C), X303.32

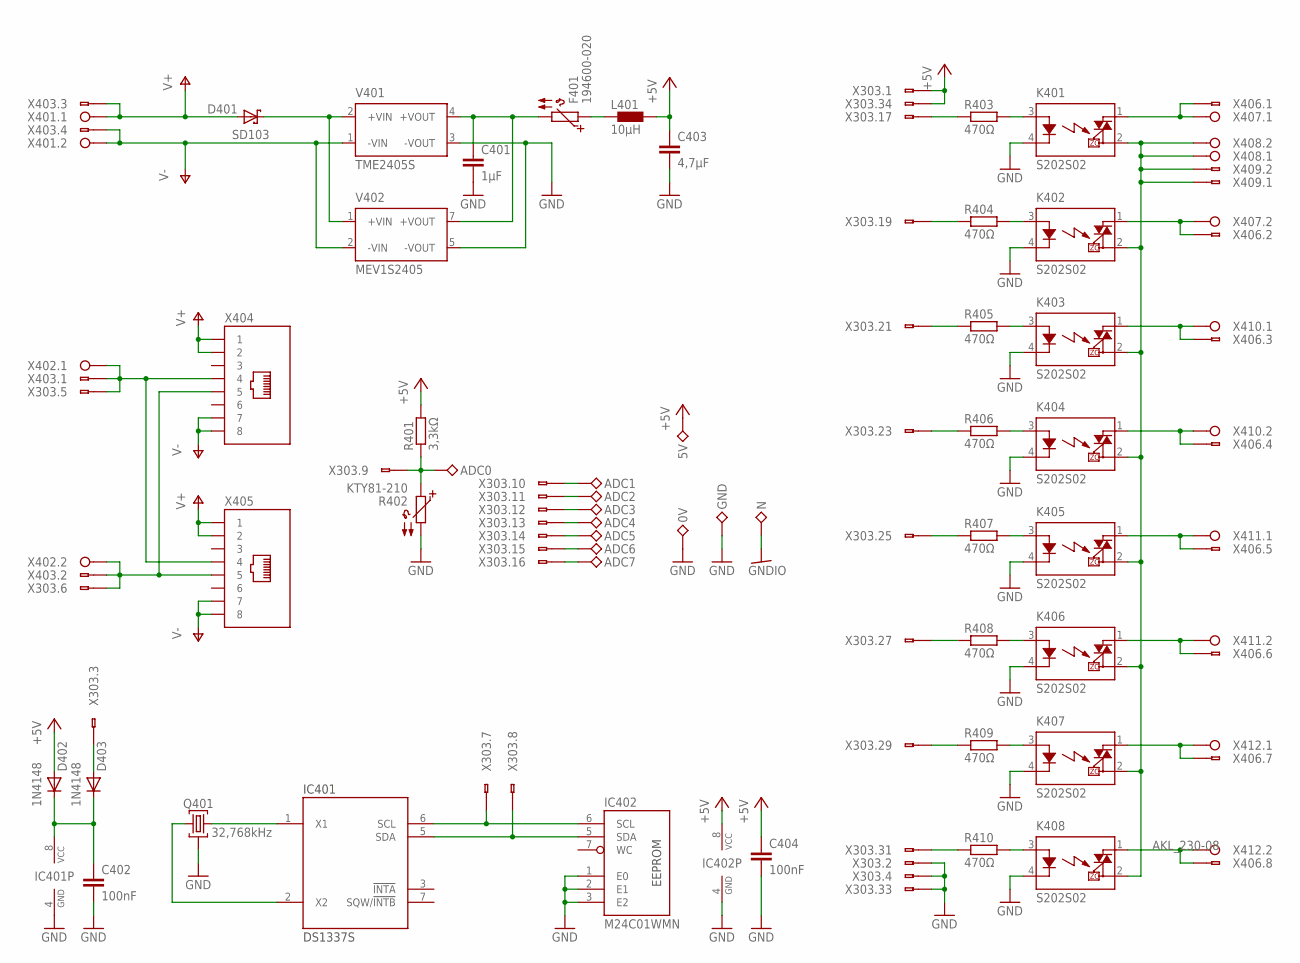
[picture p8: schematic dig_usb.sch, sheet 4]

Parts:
0V, 5V: TEST_VIA_08; VIA08
ADC0, ADC1, ADC2, ADC3, ADC4, ADC5, ADC6, ADC7: TEST_PAD_SMALL; PADS
C401: 1μF; CHIP_0805
C402, C404: 100nF; CHIP_0603
C403: 4,7μF; CHIP_0805
D401: SD103; SOD123
D402, D403: 1N4148; SOD123
F401: 194600-020; CHIP_1812
GND: TEST_VIA_08; VIA08
IC401: DS1337S; SOP08_127
IC402: M24C01WMN; SOP08_127
K401, K402, K403, K404, K405, K406, K407, K408: S202S02; SIP4
L401: 10μH; 1812AF
N: TEST_VIA_08; VIA08
Q401: 32,768kHz; MS1V-T1K
R401: 3,3kΩ; CHIP_0805
R402: KTY81-210; TO92
R403, R404, R405, R406, R407, R408, R409, R410: 470Ω; CHIP_0805
V401: TME2405S; TME-24V; MPN TME 2405S
V402: MEV1S2405; MEV1S
X303: WS34V
X401, X402, X407, X408, X410, X411, X412: RIA-73-02
X403: AKL_230-04
X404, X405: 8P8C; C-BMJ-0102
X406: AKL_230-08
X409: AKL_230-02

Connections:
+5V: 5V.1, C403.1, C404.1, D402.A, IC402.8 (VCC), L401.1, R401.2, X303.1, X303.34; also elsewhere on the board
GND: 0V.1, C401.2, C402.2, C403.2, C404.2, GND.1, IC401.4 (GND), IC402.1 (E0), IC402.2 (E1), IC402.3 (E2), IC402.4 (GND), K401.4 (K), K402.4 (K), K403.4 (K), K404.4 (K), K405.4 (K), K406.4 (K), K407.4 (K), K408.4 (K), Q401.G, R402.2, V401.3 (-VOUT), V402.5 (-VOUT), X303.2, X303.4, X303.33; also elsewhere on the board
GNDIO: N.1; also elsewhere on the board
L: K401.2 (DS2), K402.2 (DS2), K403.2 (DS2), K404.2 (DS2), K405.2 (DS2), K406.2 (DS2), K407.2 (DS2), K408.2 (DS2), X408.1, X408.2, X409.P$1, X409.P$2
unnamed: K401.3 (A), R403.2
unnamed: K402.3 (A), R404.2
unnamed: C401.1, F401.2, V401.4 (+VOUT), V402.7 (+VOUT)
unnamed: D401.K, V401.2 (+VIN), V402.1 (+VIN)
unnamed: F401.1, L401.2
unnamed: K403.3 (A), R405.2
unnamed: K404.3 (A), R406.2
unnamed: ADC1.1, X303.10
unnamed: K405.3 (A), R407.2
unnamed: K406.3 (A), R408.2
unnamed: K407.3 (A), R409.2
unnamed: C402.1, D402.K, D403.K, IC401.8 (VCC)
unnamed: K408.3 (A), R410.2
unnamed: R403.1, X303.17
unnamed: K401.1 (DS1), X406.P$1, X407.1
unnamed: K402.1 (DS1), X406.P$2, X407.2
unnamed: K403.1 (DS1), X406.P$3, X410.1
unnamed: K404.1 (DS1), X406.P$4, X410.2
unnamed: K405.1 (DS1), X406.P$5, X411.1
unnamed: R404.1, X303.19
unnamed: K406.1 (DS1), X406.P$6, X411.2
unnamed: K407.1 (DS1), X406.P$7, X412.1
unnamed: R405.1, X303.21
unnamed: R406.1, X303.23
unnamed: K408.1 (DS1), X406.P$8, X412.2
unnamed: R407.1, X303.25
unnamed: R408.1, X303.27
unnamed: R409.1, X303.29
unnamed: R410.1, X303.31
unnamed: IC401.1 (X1), Q401.2
unnamed: IC401.2 (X2), Q401.1
unnamed: D403.A, X303.3
unnamed: IC401.6 (SCL), IC402.6 (SCL), X303.7
unnamed: IC401.5 (SDA), IC402.5 (SDA), X303.8
unnamed: X303.6, X402.2, X403.P$2, X404.P$5 (5), X405.P$5 (5)
unnamed: X303.5, X402.1, X403.P$1, X404.P$4 (4), X405.P$4 (4)
unnamed: ADC0.1, R401.1, R402.1, X303.9
unnamed: ADC2.1, X303.11
unnamed: ADC3.1, X303.12
unnamed: ADC4.1, X303.13
unnamed: ADC5.1, X303.14
unnamed: ADC6.1, X303.15
unnamed: ADC7.1, X303.16
V+: D401.A, X401.1, X403.P$3, X404.P$1 (1), X404.P$2 (2), X405.P$1 (1), X405.P$2 (2)
V-: V401.1 (-VIN), V402.2 (-VIN), X401.2, X403.P$4, X404.P$7 (7), X404.P$8 (8), X405.P$7 (7), X405.P$8 (8)

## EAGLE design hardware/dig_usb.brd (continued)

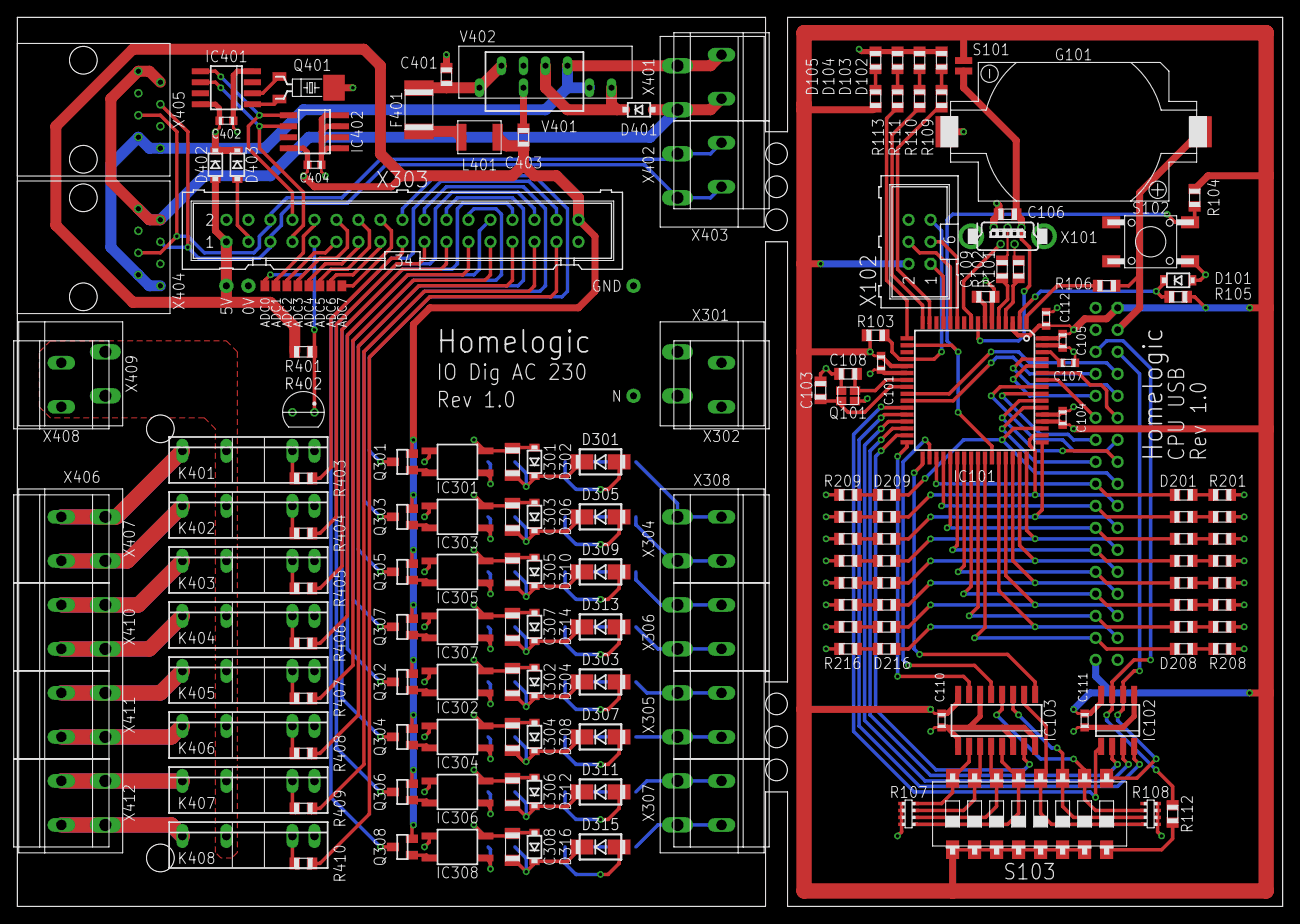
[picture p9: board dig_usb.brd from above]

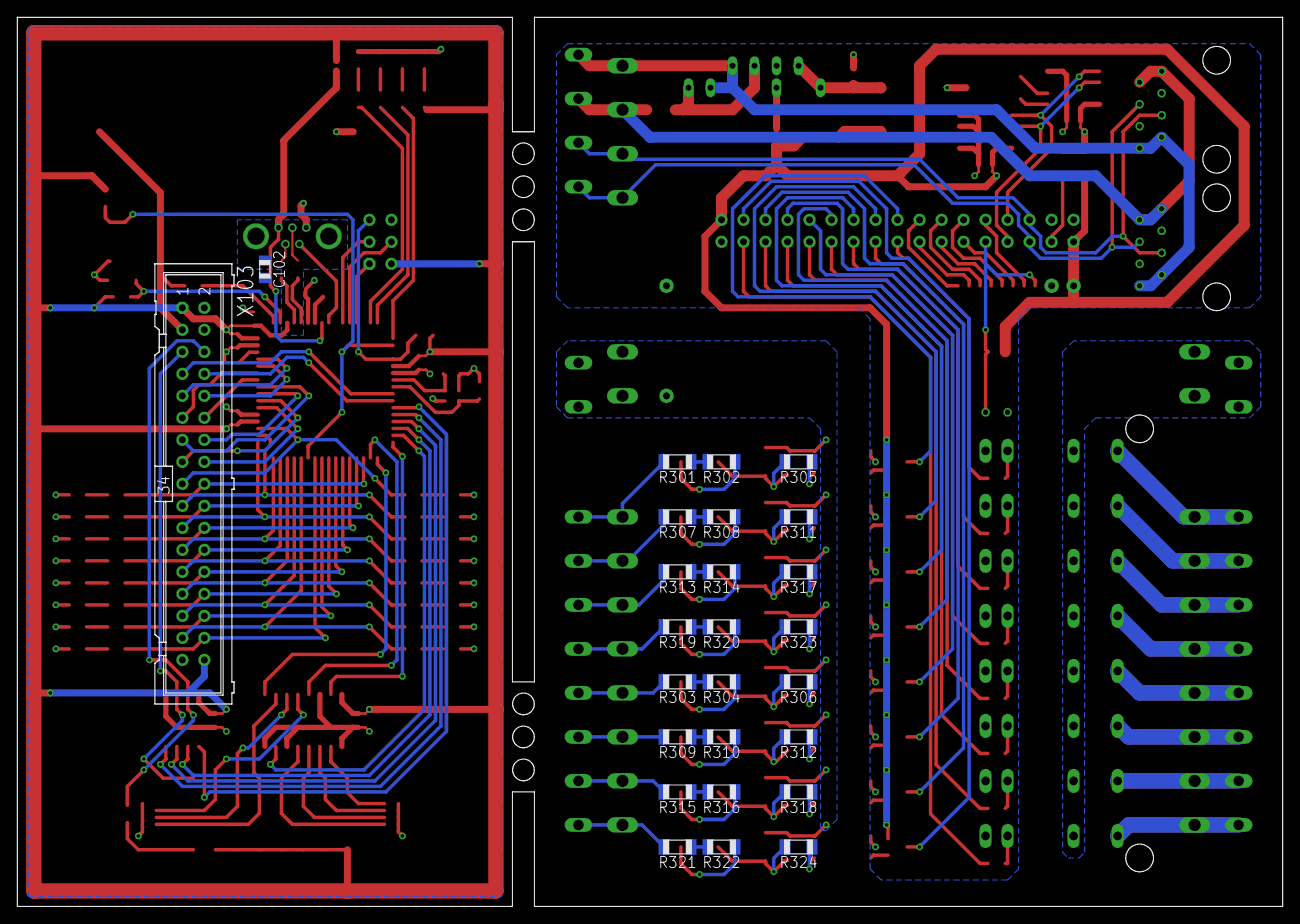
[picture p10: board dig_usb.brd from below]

Board: 2 copper layers, 146.1 x 102.6 mm, 201 parts (26 on the bottom side), 191 nets.

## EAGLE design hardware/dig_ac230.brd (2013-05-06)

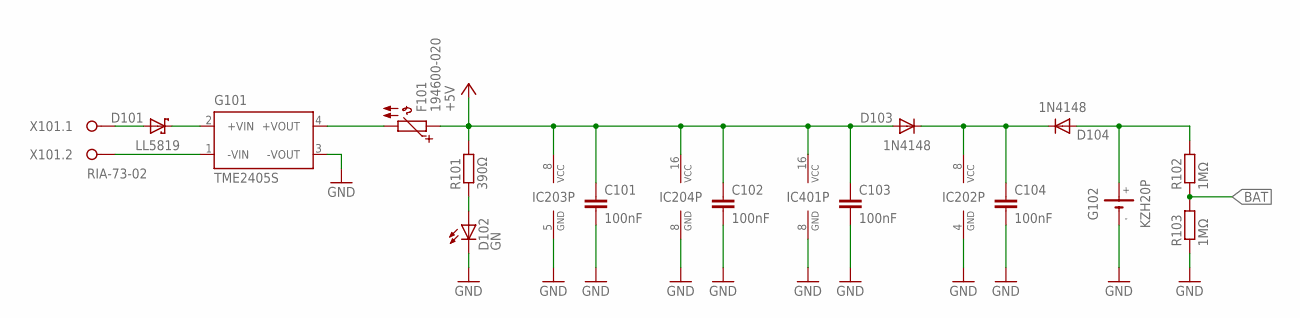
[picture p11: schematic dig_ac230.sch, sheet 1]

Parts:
C101, C102, C103, C104: 100nF; CHIP_0805
D101: LL5819; MELF
D102: GN; LED3MM
D103, D104: 1N4148; MINIMELF
F101: 194600-020; CHIP_1812
G101: TME2405S; TME-24V; MPN TME 2405S
G102: KZH20P
IC202: DS1337S; SOP08_127
IC203: MAX487CSA; SOP08_127
IC204: 74HC166D; SOP16_127
IC401: 74HC595D; SOP16_127
R101: 390Ω; CHIP_0805
R102, R103: 1MΩ; CHIP_0805
X101: RIA-73-02

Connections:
+5V: C101.1, C102.1, C103.1, D103.A, F101.1, IC203.8 (VCC), IC204.16 (VCC), IC401.16 (VCC), R101.2; also elsewhere on the board
BAT: R102.1, R103.2; also elsewhere on the board
GND: C101.2, C102.2, C103.2, C104.2, D102.K (C), G101.3 (-VOUT), G102.N (-), IC202.4 (GND), IC203.5 (GND), IC204.8 (GND), IC401.8 (GND), R103.1; also elsewhere on the board
unnamed: G101.1 (-VIN), X101.2
unnamed: D104.A, G102.P1 (+), G102.P2 (+), R102.2
unnamed: D101.K, G101.2 (+VIN)
unnamed: D101.A, X101.1
unnamed: F101.2, G101.4 (+VOUT)
unnamed: D102.A, R101.1
unnamed: C104.1, D103.K, D104.K, IC202.8 (VCC)

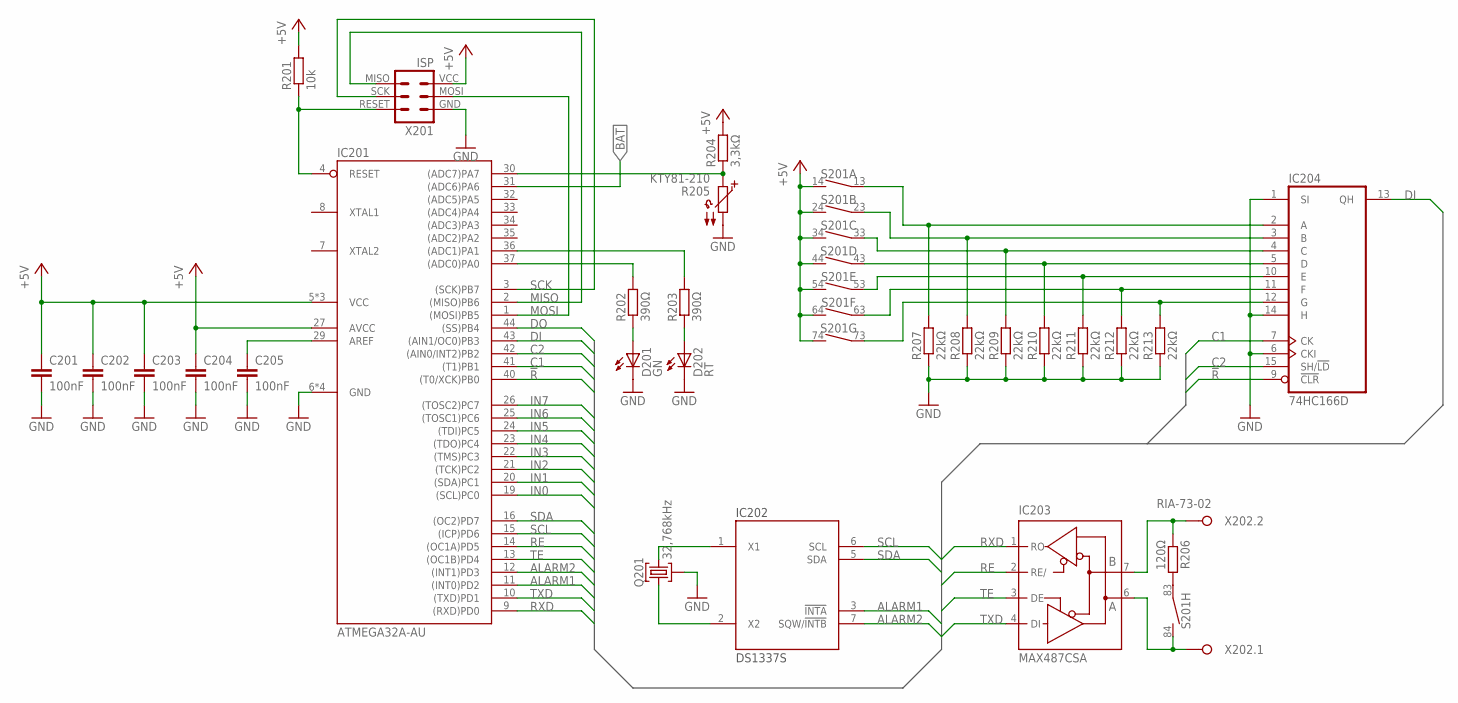
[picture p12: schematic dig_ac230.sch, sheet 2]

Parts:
C201, C202, C203, C204, C205: 100nF; CHIP_0805
D201: GN; LED3MM
D202: RT; LED3MM
IC201: ATMEGA32A-AU; QFP44_08
IC202: DS1337S; SOP08_127
IC203: MAX487CSA; SOP08_127
IC204: 74HC166D; SOP16_127
Q201: 32,768kHz; MS1V-T1K
R201: 10k; CHIP_0805
R202, R203: 390Ω; CHIP_0805
R204: 3,3kΩ; CHIP_0805
R205: KTY81-210; TO92
R206: 120Ω; CHIP_0805
R207, R208, R209, R210, R211, R212, R213: 22kΩ; CHIP_0805
S201: DP08
X201: ISP; ML6L
X202: RIA-73-02

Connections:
!R: IC201.40 ((T0/XCK)PB0), IC204.9 (!CLR); also elsewhere on the board
+5V: C201.1, C202.1, C203.1, C204.1, IC201.5 (VCC), IC201.17 (VCC), IC201.27 (AVCC), IC201.38 (VCC), R201.2, R204.2, S201.14 (4), S201.24 (4), S201.34 (4), S201.44 (4), S201.54 (4), S201.64 (4), S201.74 (4), X201.VCC; also elsewhere on the board
ALARM1: IC201.11 ((INT0)PD2), IC202.3 (!INTA)
ALARM2: IC201.12 ((INT1)PD3), IC202.7 (SQW/!INTB)
BAT: IC201.31 ((ADC6)PA6); also elsewhere on the board
C1: IC201.41 ((T1)PB1), IC204.7 (CK); also elsewhere on the board
C2: IC201.42 ((AIN0/INT2)PB2), IC204.15 (SH/!LD); also elsewhere on the board
DI: IC201.43 ((AIN1/OC0)PB3), IC204.13 (QH)
DO: IC201.44 ((SS)PB4); also elsewhere on the board
GND: C201.2, C202.2, C203.2, C204.2, C205.2, D201.K (C), D202.K (C), IC201.6 (GND), IC201.18 (GND), IC201.28 (GND), IC201.39 (GND), IC204.1 (SI), IC204.6 (CKI), IC204.14 (H), Q201.G, R205.2, R207.1, R208.1, R209.1, R210.1, R211.1, R212.1, R213.1, X201.GND; also elsewhere on the board
IN0: IC201.19 ((SCL)PC0); also elsewhere on the board
IN1: IC201.20 ((SDA)PC1); also elsewhere on the board
IN2: IC201.21 ((TCK)PC2); also elsewhere on the board
IN3: IC201.22 ((TMS)PC3); also elsewhere on the board
IN4: IC201.23 ((TDO)PC4); also elsewhere on the board
IN5: IC201.24 ((TDI)PC5); also elsewhere on the board
IN6: IC201.25 ((TOSC1)PC6); also elsewhere on the board
IN7: IC201.26 ((TOSC2)PC7); also elsewhere on the board
MISO: IC201.2 ((MISO)PB6), X201.MISO
MOSI: IC201.1 ((MOSI)PB5), X201.MOSI
unnamed: IC203.6 (A), S201.84 (4), X202.1
unnamed: IC203.7 (B), R206.1, X202.2
unnamed: C205.1, IC201.29 (AREF)
unnamed: IC204.2 (A), R207.2, S201.13 (3)
unnamed: IC204.3 (B), R208.2, S201.23 (3)
unnamed: IC204.4 (C), R209.2, S201.33 (3)
unnamed: IC204.5 (D), R210.2, S201.43 (3)
unnamed: IC204.10 (E), R211.2, S201.53 (3)
unnamed: IC204.11 (F), R212.2, S201.63 (3)
unnamed: IC204.12 (G), R213.2, S201.73 (3)
unnamed: R206.2, S201.83 (3)
unnamed: IC201.4 (RESET), R201.1, X201.RESET
unnamed: IC201.30 ((ADC7)PA7), R204.1, R205.1
unnamed: D201.A, R202.1
unnamed: D202.A, R203.1
unnamed: IC201.37 ((ADC0)PA0), R202.2
unnamed: IC201.36 ((ADC1)PA1), R203.2
unnamed: IC202.1 (X1), Q201.2
unnamed: IC202.2 (X2), Q201.1
RE: IC201.14 ((OC1A)PD5), IC203.2 (RE/)
RXD: IC201.9 ((RXD)PD0), IC203.1 (RO)
SCK: IC201.3 ((SCK)PB7), X201.SCK
SCL: IC201.15 ((ICP)PD6), IC202.6 (SCL)
SDA: IC201.16 ((OC2)PD7), IC202.5 (SDA)
TE: IC201.13 ((OC1B)PD4), IC203.3 (DE)
TXD: IC201.10 ((TXD)PD1), IC203.4 (DI)


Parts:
D301, D302, D303, D304, D305, D306, D307, D308: GN; LED3MM
IC301, IC302, IC303, IC304, IC305, IC306, IC307, IC308: LTV-354T; SOP04_254
R301, R302, R303, R304, R305, R306, R307, R308: 390Ω; CHIP_0805
R309, R310, R311, R312, R313, R314, R315, R316, R317, R318, R319, R320, R321, R322, R323, R324: 120kΩ; CHIP_1206
T301, T302, T303, T304, T305, T306, T307, T308: BCR191; SOT23
X301, X302, X303, X304, X305: RIA-73-02

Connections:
+5V: T301.2 (E), T302.2 (E), T303.2 (E), T304.2 (E), T305.2 (E), T306.2 (E), T307.2 (E), T308.2 (E); also elsewhere on the board
GND: D301.K (C), D302.K (C), D303.K (C), D304.K (C), D305.K (C), D306.K (C), D307.K (C), D308.K (C), IC301.3 (E), IC302.3 (E), IC303.3 (E), IC304.3 (E), IC305.3 (E), IC306.3 (E), IC307.3 (E), IC308.3 (E); also elsewhere on the board
GNDIO: R317.1, R318.1, R319.1, R320.1, R321.1, R322.1, R323.1, R324.1, X301.1, X301.2
IN0: R301.2, T301.3 (C); also elsewhere on the board
IN1: R302.2, T302.3 (C); also elsewhere on the board
IN2: R303.2, T303.3 (C); also elsewhere on the board
IN3: R304.2, T304.3 (C); also elsewhere on the board
IN4: R305.2, T305.3 (C); also elsewhere on the board
IN5: R306.2, T306.3 (C); also elsewhere on the board
IN6: R307.2, T307.3 (C); also elsewhere on the board
IN7: R308.2, T308.3 (C); also elsewhere on the board
unnamed: R309.2, X302.2
unnamed: IC301.1 (A), R309.1
unnamed: IC301.2 (K), R317.2
unnamed: R310.2, X302.1
unnamed: IC302.1 (A), R310.1
unnamed: IC302.2 (K), R318.2
unnamed: R311.2, X303.2
unnamed: IC303.1 (A), R311.1
unnamed: IC303.2 (K), R319.2
unnamed: R312.2, X303.1
unnamed: IC304.1 (A), R312.1
unnamed: IC304.2 (K), R320.2
unnamed: R313.2, X304.2
unnamed: IC305.1 (A), R313.1
unnamed: IC305.2 (K), R321.2
unnamed: R314.2, X304.1
unnamed: D304.A, R304.1
unnamed: IC306.1 (A), R314.1
unnamed: D303.A, R303.1
unnamed: IC306.2 (K), R322.2
unnamed: D302.A, R302.1
unnamed: IC307.1 (A), R315.1
unnamed: D301.A, R301.1
unnamed: IC307.2 (K), R323.2
unnamed: IC304.4 (C), T304.1 (B)
unnamed: D305.A, R305.1
unnamed: R315.2, X305.2
unnamed: D306.A, R306.1
unnamed: R316.2, X305.1
unnamed: D307.A, R307.1
unnamed: IC303.4 (C), T303.1 (B)
unnamed: IC308.1 (A), R316.1
unnamed: IC302.4 (C), T302.1 (B)
unnamed: IC301.4 (C), T301.1 (B)
unnamed: D308.A, R308.1
unnamed: IC308.2 (K), R324.2
unnamed: IC305.4 (C), T305.1 (B)
unnamed: IC306.4 (C), T306.1 (B)
unnamed: IC307.4 (C), T307.1 (B)
unnamed: IC308.4 (C), T308.1 (B)


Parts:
D401, D402, D403, D404, D405, D406, D407, D408: GN; LED3MM
IC401: 74HC595D; SOP16_127
K401, K402, K403, K404, K405, K406, K407, K408: S202S02; SIP4
R401, R402, R403, R404, R405, R406, R407, R408: 180Ω; CHIP_0805
X401, X402, X403, X404, X405: RIA-73-02

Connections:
!R: IC401.10 (!SCLR); also elsewhere on the board
C1: IC401.11 (SCK); also elsewhere on the board
C2: IC401.12 (RCK); also elsewhere on the board
DO: IC401.14 (SI); also elsewhere on the board
GND: IC401.13 (!OE), K401.4 (K), K402.4 (K), K403.4 (K), K404.4 (K), K405.4 (K), K406.4 (K), K407.4 (K), K408.4 (K); also elsewhere on the board
L: K401.2 (DS2), K402.2 (DS2), K403.2 (DS2), K404.2 (DS2), K405.2 (DS2), K406.2 (DS2), K407.2 (DS2), K408.2 (DS2), X401.1, X401.2
unnamed: D401.K (C), K401.3 (A)
unnamed: D402.K (C), K402.3 (A)
unnamed: D403.K (C), K403.3 (A)
unnamed: D404.K (C), K404.3 (A)
unnamed: D405.K (C), K405.3 (A)
unnamed: D406.K (C), K406.3 (A)
unnamed: D407.K (C), K407.3 (A)
unnamed: D408.K (C), K408.3 (A)
unnamed: IC401.15 (QA), R401.1
unnamed: IC401.1 (QB), R402.1
unnamed: IC401.2 (QC), R403.1
unnamed: IC401.3 (QD), R404.1
unnamed: IC401.4 (QE), R405.1
unnamed: IC401.5 (QF), R406.1
unnamed: IC401.6 (QG), R407.1
unnamed: IC401.7 (QH), R408.1
unnamed: K401.1 (DS1), X402.1
unnamed: K402.1 (DS1), X402.2
unnamed: K403.1 (DS1), X403.1
unnamed: K404.1 (DS1), X403.2
unnamed: K405.1 (DS1), X404.1
unnamed: K406.1 (DS1), X404.2
unnamed: K407.1 (DS1), X405.1
unnamed: K408.1 (DS1), X405.2
unnamed: D401.A, R401.2
unnamed: D402.A, R402.2
unnamed: D403.A, R403.2
unnamed: D404.A, R404.2
unnamed: D405.A, R405.2
unnamed: D406.A, R406.2
unnamed: D407.A, R407.2
unnamed: D408.A, R408.2



Board: 2 copper layers, 100.0 x 85.0 mm, 126 parts (21 on the bottom side), 127 nets.

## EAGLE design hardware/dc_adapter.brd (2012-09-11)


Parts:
D1: SCHOTTKY-DIODEDO35-7; DO35-7
F1: LP60-020
LED1: LED3MM
R1: 390Ω; 0204V
V101: TME2405S; TME-24V; MPN TME 2405S
X1: ST4; STG4

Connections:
unnamed: V101.1 (-VIN), X1.1
unnamed: D1.C, V101.2 (+VIN)
unnamed: D1.A, X1.2
unnamed: F1.P$2 (2), V101.4 (+VOUT)
unnamed: LED1.K (C), V101.3 (-VOUT), X1.3
unnamed: LED1.A, R1.1
unnamed: F1.P$1 (1), R1.2, X1.4


Board: 2 copper layers, 21.6 x 18.7 mm, 6 parts (0 on the bottom side), 7 nets.

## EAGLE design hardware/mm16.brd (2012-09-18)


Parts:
C1, C101, C102, C103: 100nF; C025-025X050
D1, D2: 1N4148-7; DO35-7@1
D3: SCHOTTKY-DIODEDO35-7; DO35-7
F1: LP60-020
G1: KZH20PCB-V
IC101: ATMEGA32-PU; DIL40
IC102: DS1337; DIL08
IC103: MAX483CPA; DIL08
LED1: LED3MM
Q1: 32,768kHz; TC38H
R1: 120Ω; 0204V
R2: 390Ω; 0204V
R101: 10k; 0204V
S1: P103
SV101: AVR_ISP6; ML6
V1: TME2405S; TME-24V; MPN TME 2405S
X1: WS16V
X5, X6: WAGO_236-402

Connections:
!R: IC101.21 ((OC2)PD7), X1.5, X1.6
+5V: C101.1, C102.1, C103.1, D1.A, F1.P$1 (1), IC101.10 (VCC), IC101.30 (AVCC), IC103.8 (VCC), R2.2, R101.2, SV101.VCC, X1.1, X1.2, X1.3, X1.4
ALARM1: IC101.4 ((AIN1/OC0)PB3), IC102.3 (!INTA)
ALARM2: IC101.3 ((AIN0/INT2)PB2), IC102.7 (SQW/!INTB)
C1: IC101.18 ((OC1B)PD4), X1.7, X1.8
C2: IC101.19 ((OC1A)PD5), X1.9, X1.10
D: IC101.20 ((ICP)PD6), X1.11, X1.12
GND: C1.2, C101.2, C102.2, C103.2, G1.-, IC101.11 (GND), IC101.31 (GND), IC102.4 (GND), IC103.5 (GND), LED1.K (C), S1.C, SV101.GND, V1.3 (-VOUT), X1.13, X1.14, X1.15, X1.16; also elsewhere on the board
IN0: IC101.40 ((ADC0)PA0); also elsewhere on the board
IN1: IC101.39 ((ADC1)PA1); also elsewhere on the board
IN2: IC101.38 ((ADC2)PA2); also elsewhere on the board
IN3: IC101.37 ((ADC3)PA3); also elsewhere on the board
IN4: IC101.36 ((ADC4)PA4); also elsewhere on the board
IN5: IC101.35 ((ADC5)PA5); also elsewhere on the board
IN6: IC101.34 ((ADC6)PA6); also elsewhere on the board
IN7: IC101.33 ((ADC7)PA7); also elsewhere on the board
IN8: IC101.29 ((TOSC2)PC7); also elsewhere on the board
IN9: IC101.28 ((TOSC1)PC6); also elsewhere on the board
IN10: IC101.27 ((TDI)PC5); also elsewhere on the board
IN11: IC101.26 ((TDO)PC4); also elsewhere on the board
IN12: IC101.25 ((TMS)PC3); also elsewhere on the board
IN13: IC101.24 ((TCK)PC2); also elsewhere on the board
IN14: IC101.23 ((SDA)PC1); also elsewhere on the board
IN15: IC101.22 ((SCL)PC0); also elsewhere on the board
unnamed: V1.1 (-VIN), X5.A2, X5.B2
unnamed: IC103.6 (A), R1.1, X6.A1, X6.B1
unnamed: D2.A, G1.+1 (+), G1.+2 (+)
unnamed: IC103.7 (B), R1.2, X6.A2, X6.B2
unnamed: D3.C, V1.2 (+VIN)
unnamed: D3.A, X5.A1, X5.B1
unnamed: F1.P$2 (2), V1.4 (+VOUT)
unnamed: IC101.9 (RESET), R101.1, SV101.RESET
unnamed: LED1.A, R2.1
unnamed: IC101.15 ((TXD)PD1), IC103.4 (DI)
unnamed: IC101.14 ((RXD)PD0), IC103.1 (RO)
unnamed: IC101.17 ((INT1)PD3), IC103.2 (RE/)
unnamed: IC101.16 ((INT0)PD2), IC103.3 (DE)
unnamed: IC101.6 ((MOSI)PB5), S1.8, SV101.MOSI
unnamed: IC101.7 ((MISO)PB6), S1.2, SV101.MISO
unnamed: IC101.8 ((SCK)PB7), S1.4, SV101.SCK
unnamed: IC102.1 (X1), Q1.1
unnamed: IC102.2 (X2), Q1.2
unnamed: IC101.5 ((SS)PB4), S1.1
SCL: IC101.1 ((T0/XCK)PB0), IC102.6 (SCL)
SDA: IC101.2 ((T1)PB1), IC102.5 (SDA)
VCC: C1.1, D1.C, D2.C, IC102.8 (VCC)


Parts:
D201, D202, D203, D204, D205, D206, D207, D208, D209, D210, D211, D212, D213, D214, D215, D216: 1N4148-V; DO35-V
IC201, IC202, IC203, IC204: LTV847; DIL16
R201, R202, R203, R204, R205, R206, R207, R208, R209, R210, R211, R212, R213, R214, R215, R216: 220kΩ; 0204V
X2, X3: WAGO_236-408
X4: WAGO_236-401

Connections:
GND: IC201.9 (EMIT), IC201.11 (EMIT), IC201.13 (EMIT), IC201.15 (EMIT), IC202.9 (EMIT), IC202.11 (EMIT), IC202.13 (EMIT), IC202.15 (EMIT), IC203.9 (EMIT), IC203.11 (EMIT), IC203.13 (EMIT), IC203.15 (EMIT), IC204.9 (EMIT), IC204.11 (EMIT), IC204.13 (EMIT), IC204.15 (EMIT); also elsewhere on the board
GNDIO: R201.1, R202.1, R203.1, R204.1, R205.1, R206.1, R207.1, R208.1, R209.1, R210.1, R211.1, R212.1, R213.1, R214.1, R215.1, R216.1, X4.A1 (A), X4.B1 (B)
IN0: IC201.10 (COL); also elsewhere on the board
IN1: IC201.12 (COL); also elsewhere on the board
IN2: IC201.14 (COL); also elsewhere on the board
IN3: IC201.16 (COL); also elsewhere on the board
IN4: IC202.10 (COL); also elsewhere on the board
IN5: IC202.12 (COL); also elsewhere on the board
IN6: IC202.14 (COL); also elsewhere on the board
IN7: IC202.16 (COL); also elsewhere on the board
IN8: IC203.10 (COL); also elsewhere on the board
IN9: IC203.12 (COL); also elsewhere on the board
IN10: IC203.14 (COL); also elsewhere on the board
IN11: IC203.16 (COL); also elsewhere on the board
IN12: IC204.10 (COL); also elsewhere on the board
IN13: IC204.12 (COL); also elsewhere on the board
IN14: IC204.14 (COL); also elsewhere on the board
IN15: IC204.16 (COL); also elsewhere on the board
unnamed: D201.2 (C), IC201.7 (A)
unnamed: IC201.8 (C), R201.2
unnamed: D202.2 (C), IC201.5 (A)
unnamed: IC201.6 (C), R202.2
unnamed: D203.2 (C), IC201.3 (A)
unnamed: IC201.4 (C), R203.2
unnamed: D204.2 (C), IC201.1 (A)
unnamed: IC201.2 (C), R204.2
unnamed: D205.2 (C), IC202.7 (A)
unnamed: IC202.8 (C), R205.2
unnamed: D206.2 (C), IC202.5 (A)
unnamed: IC202.6 (C), R206.2
unnamed: D207.2 (C), IC202.3 (A)
unnamed: IC202.4 (C), R207.2
unnamed: D208.2 (C), IC202.1 (A)
unnamed: IC202.2 (C), R208.2
unnamed: D209.2 (C), IC203.7 (A)
unnamed: IC203.8 (C), R209.2
unnamed: D210.2 (C), IC203.5 (A)
unnamed: IC203.6 (C), R210.2
unnamed: D211.2 (C), IC203.3 (A)
unnamed: IC203.4 (C), R211.2
unnamed: D212.2 (C), IC203.1 (A)
unnamed: IC203.2 (C), R212.2
unnamed: D213.2 (C), IC204.7 (A)
unnamed: IC204.8 (C), R213.2
unnamed: D214.2 (C), IC204.5 (A)
unnamed: IC204.6 (C), R214.2
unnamed: D215.2 (C), IC204.3 (A)
unnamed: IC204.4 (C), R215.2
unnamed: D216.2 (C), IC204.1 (A)
unnamed: IC204.2 (C), R216.2
unnamed: D204.1 (A), X2.A5, X2.B5
unnamed: D203.1 (A), X2.A6, X2.B6
unnamed: D202.1 (A), X2.A7, X2.B7
unnamed: D201.1 (A), X2.A8, X2.B8
unnamed: D205.1 (A), X2.A4, X2.B4
unnamed: D206.1 (A), X2.A3, X2.B3
unnamed: D207.1 (A), X2.A2, X2.B2
unnamed: D208.1 (A), X2.A1, X2.B1
unnamed: D216.1 (A), X3.A1, X3.B1
unnamed: D215.1 (A), X3.A2, X3.B2
unnamed: D214.1 (A), X3.A3, X3.B3
unnamed: D213.1 (A), X3.A4, X3.B4
unnamed: D212.1 (A), X3.A5, X3.B5
unnamed: D211.1 (A), X3.A6, X3.B6
unnamed: D209.1 (A), X3.A8, X3.B8
unnamed: D210.1 (A), X3.A7, X3.B7


Board: 2 copper layers, 100.0 x 80.0 mm, 62 parts (0 on the bottom side), 95 nets.

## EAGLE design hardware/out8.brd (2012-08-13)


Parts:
C101: 100nF; C025-025X050
F1, F2, F3, F4, F5, F6, F7, F8: 2T; TR5
IC1: 74HC595N; DIL16
K301, K302, K303, K304, K305, K306, K307, K308: S202S02; SIP4
LED1, LED2, LED3, LED4, LED5, LED6, LED7, LED8: LED3MM
R301, R302, R303, R304, R305, R306, R307, R308: 180Ω; 0204/7
X1, X2: WAGO_236-408
X101, X102: WS16V

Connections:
!R: IC1.10 (SCL), X101.5, X101.6, X102.5, X102.6
+5V: C101.1, IC1.16 (VCC), X101.1, X101.2, X101.3, X101.4, X102.1, X102.2, X102.3, X102.4
C1: IC1.11 (SCK), X101.7, X101.8, X102.7, X102.8
C2: IC1.12 (RCK), X101.9, X101.10, X102.9, X102.10
D: IC1.14 (SER), X101.11, X101.12
GND: C101.2, IC1.8 (GND), IC1.13 (G), K301.4 (K), K302.4 (K), K303.4 (K), K304.4 (K), K305.4 (K), K306.4 (K), K307.4 (K), K308.4 (K), X101.13, X101.14, X101.15, X101.16, X102.13, X102.14, X102.15, X102.16
unnamed: IC1.15 (QA), R301.1
unnamed: IC1.1 (QB), R302.1
unnamed: IC1.2 (QC), R303.1
unnamed: IC1.3 (QD), R304.1
unnamed: IC1.4 (QE), R305.1
unnamed: IC1.5 (QF), R306.1
unnamed: IC1.6 (QG), R307.1
unnamed: IC1.7 (QH), R308.1
unnamed: F1.1, K301.1 (DS1)
unnamed: F1.2, X1.A1, X1.B1
unnamed: K301.2 (DS2), X1.A2, X1.B2
unnamed: F2.1, K302.1 (DS1)
unnamed: F2.2, X1.A3, X1.B3
unnamed: K302.2 (DS2), X1.A4, X1.B4
unnamed: F3.1, K303.1 (DS1)
unnamed: F3.2, X1.A5, X1.B5
unnamed: K301.3 (A), LED1.K (C)
unnamed: K302.3 (A), LED2.K (C)
unnamed: K303.3 (A), LED3.K (C)
unnamed: K304.3 (A), LED4.K (C)
unnamed: K305.3 (A), LED5.K (C)
unnamed: K306.3 (A), LED6.K (C)
unnamed: K307.3 (A), LED7.K (C)
unnamed: K308.3 (A), LED8.K (C)
unnamed: K303.2 (DS2), X1.A6, X1.B6
unnamed: F4.1, K304.1 (DS1)
unnamed: F4.2, X1.A7, X1.B7
unnamed: K304.2 (DS2), X1.A8, X1.B8
unnamed: F5.1, K305.1 (DS1)
unnamed: F5.2, X2.A1, X2.B1
unnamed: K305.2 (DS2), X2.A2, X2.B2
unnamed: F6.1, K306.1 (DS1)
unnamed: F6.2, X2.A3, X2.B3
unnamed: K306.2 (DS2), X2.A4, X2.B4
unnamed: F7.1, K307.1 (DS1)
unnamed: F7.2, X2.A5, X2.B5
unnamed: K307.2 (DS2), X2.A6, X2.B6
unnamed: F8.1, K308.1 (DS1)
unnamed: F8.2, X2.A7, X2.B7
unnamed: K308.2 (DS2), X2.A8, X2.B8
unnamed: IC1.9 (QH*), X102.11, X102.12
unnamed: LED1.A, R301.2
unnamed: LED2.A, R302.2
unnamed: LED3.A, R303.2
unnamed: LED4.A, R304.2
unnamed: LED5.A, R305.2
unnamed: LED6.A, R306.2
unnamed: LED7.A, R307.2
unnamed: LED8.A, R308.2


Board: 2 copper layers, 100.0 x 80.0 mm, 38 parts (0 on the bottom side), 55 nets.

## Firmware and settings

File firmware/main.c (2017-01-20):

/*
 * Copyright (C) 2013 - 2017 Stephan Reinhard <Stephan-Reinhard@gmx.de>
 *
 * This file is part of Homelogic.
 *
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
 * You should have received a copy of the GNU General Public License
 * along with Homelogic.  If not, see <http://www.gnu.org/licenses/>.
 */

#include <stdlib.h>
#include <avr/eeprom.h>
#include "main.h"
#include "i2c.h"
#include "rtc.h"
#include "bus.h"
#include "prog.h"
#include "led.h"
#include "error.h"
#include "adc.h"
#include "usb.h"



struct state_s state;
volatile prog_write_t prog_write;
bool output_lock = false;




/* Interruptroutine für 1ms Timer
 */
ISR(TIMER2_COMP_vect) {
        static uint8_t intimer[INPUT_COUNT];
        static uint16_t timerbase = 0;

        if (bus.tx_lock) bus.tx_lock--;

        if (!(timerbase % 10)) progc.tick.f001++;
        if (!(timerbase % 100)) progc.tick.f01++;
        if (!(timerbase % 1000)) progc.tick.f1++;
        if (!(timerbase % 10000)) progc.tick.f10++;

        if (!(timerbase % 250)) led_control();
        if (!(timerbase % 10000)) timerbase = 0;
        timerbase++;

#ifndef RTC_USE_SQW
        if (rtc_update_time) rtc_update_time--;
#endif


        for (int8_t i = 0; i < INPUT_COUNT; i++) {
                if (get_input(i)) {
                        if (intimer[i] < INPUT_DEBOUNCE) {
                                intimer[i] += INPUT_DEBOUNCE_ON_MUL;
                        } else {
                                inputs[i >> 3] |= (1 << i % 8);
                        }
                } else {
                        if (intimer[i]) {
                                intimer[i]--;
                        } else {
                                inputs[i >> 3] &= ~(1 << i % 8);
                        }
                }
        }

}




void write_outputs(void)
{
        if (output_lock) {
                for (uint8_t i = 0; i < sizeof(outputs) / sizeof(*outputs); i++)
                        outputs[i] = 0;
        }

#ifdef SHIFT_OUTPUT
        PIN_CLR(C2);

        for (int8_t i = OUTPUT_COUNT - 1; i >= 0; i--) {
                PIN_CLR(C1);
                if (outputs[i >> 3] & (1 << i % 8)) {
                        PIN_SET(DO);
                } else {
                        PIN_CLR(DO);
                }
                PIN_SET(C1);
        }

        PIN_SET(C2);
#endif //SHIFT_OUTPUT

#ifdef PORT_OUTPUT
        for (uint8_t i = 0; i < OUTPUT_COUNT; i++) {
                set_output(i, outputs[i >> 3] & (1 << i % 8));
        }
#endif //PORT_OUTPUT
}




int __attribute__ ((OS_main)) main (void) {
        /* Bei allen neueren AVRs bleibt der Watchdog auch nach dem Reset aktiv.
         * Deswegen muss er schnellstmöglich abgeschaltet werden. Die avr-libc
         * empfiehlt eine Funktion in der Sektion .init3, aber mein bisheriger
         * Test hat gezeig, dass das hier reicht.
         */
        uint8_t mcusr = MCUSR;
        MCUSR = 0; // WDRF muss vorher gelöscht werden
        wdt_disable();


        init_pin();

#ifdef BOOTLOADER_SUPPORT
        if (PIN_IS_LOW(BTL)) {
                PIN_SET(LED_RD);
                PIN_SET(LED_YE);
                PIN_SET(LED_GN);
                _delay_ms(2000);
                PIN_CLR(LED_RD);
                PIN_CLR(LED_YE);
                bootloader();
        }
#endif


        led.green = ls_off;
        led.yellow = ls_off;
        led.red = ls_on;

        // Timer2 Initialisiegung
        SFR_SET(WGM21);
        TC2_SET_PRESCALER();
        OCR2 = TC2_VALUE;
        SFR_SET(OCIE2);


        // Initialisierung des AD - Wandlers
        SFR_SET(REFS0);
        SFR_SET(REFS1);
        ADC_SET_PRESCALER();

        // Adressdecodierung wird nur nach dem Reset durchgeführt
        adr = adr_read();

        // Für bus_init() muss adr gesetzt sein
        bus_init();

        // Reset Shiftregister
        PIN_CLR(C2);
        PIN_CLR(R);
        PIN_SET(C2);
        PIN_SET(R);

        // Interrupts ein
        sei();

#ifdef USB_SUPPORT
        usb_init();
#endif


#ifdef RTC_SUPPORT
        /* RTC Control register einstellen mit
         * Interrupts an auf ausgang ALARM1
         * SQW auf 1HZ default 32kHz
         */
        rtc_write_control(0);
        rtc_update_clock();
#endif

        bus_send_message_sync("READY", 0xFF, NULL);
        bus_command_identify(0xFF, NULL);

#ifdef RTC_SUPPORT
        // Sende die aktuelle Systemzeit
        bus_send_message_async("RTC", 0xFF, "%s-%02u.%02u.%02u-%02u:%02u:%02u",
                               rtc_day(),
                               clock.date,
                               clock.month,
                               clock.year,
                               clock.hours,
                               clock.minutes,
                               clock.seconds
                               );
#endif


        prog_write.len = 0;
        state.current = ps_stop;
        // Wenn ein Watchdog ausgelöst wurde, soll das Programm nicht automatisch starten
        state.coming = mcusr & (1 << WDRF) ? ps_stop : ps_run;
        state.step = false;
        wdt_enable(WDTO_2S);

        led.red = ls_off;
        while(1) {
                if (state.current != state.coming) {
                        switch (state.coming) {
                        case ps_stop:
                                prog_deinit();
                                bus_send_message_sync("STAT", 0xFF, "STOP");
                                led.yellow = ls_off;
                                break;

                        case ps_run:
                                if (error(prog_init())) {
                                        state.coming = ps_stop;
                                } else {
                                        bus_send_message_sync("STAT", 0xFF, "RUN");
                                        led.yellow = ls_on;
                                }
                                break;

                        case ps_debug:
                                if (error(prog_init())) {
                                        state.coming = ps_stop;
                                } else {
                                        bus_send_message_sync("STAT", 0xFF, "DEBUG");
                                        led.yellow = ls_blink;
                                }
                                break;
                        }
                        state.current = state.coming;
                }

                switch (state.current) {
                case ps_stop:
                        if (prog_write.len) {
                                led.red = ls_blink_fast;

                                char str[40];
                                uint8_t len;

                                ATOMIC_BLOCK(ATOMIC_RESTORESTATE) {
                                        eeprom_write_block((void *)prog_write.data, (void *)prog_write.pos, prog_write.len);
                                        len = bus_encode_prog_message(str, sizeof(str));
                                        prog_write.len = 0;
                                }

                                bus_send_raw_sync(str, len);
                                led.red = ls_off;
                        }
                        break;

                case ps_run:
                case ps_debug:
                        progc.ip = 0;
                        prog_execute((prog_register_t){0, false}, 0);
                        prog_periphery_sync();
                        write_outputs();
                        break;

                default:
                        led.yellow = ls_blink;
                        led.red = ~ls_blink;
                        break;
                }


                yield();
        }
}





/* Von yield werden alle wichtigen nebenläufigen Funktionen aufgerufen.
 * Diese Funktion muss von der Hauptschleife und alle anderen Warteschleifen
 * aus aufgerufen werden.
 */
void yield()
{

        bus_flush_send_buffer();

#ifdef RTC_SUPPORT
        rtc_update_clock();
#endif

        hardware_monitor();

#ifdef USB_SUPPORT
        usb_task();
#endif

#ifdef BOOTLOADER_SUPPORT
        if (PIN_IS_LOW(BTL)) {
                reset();
        }
#endif

        wdt_reset();
}

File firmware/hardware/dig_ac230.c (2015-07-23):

/*
 * Copyright (C) 2014 Stephan Reinhard <Stephan-Reinhard@gmx.de>
 *
 * This file is part of Homelogic.
 *
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
 * You should have received a copy of the GNU General Public License
 * along with Homelogic.  If not, see <http://www.gnu.org/licenses/>.
 */

#include "../hardware.h"
#include "../adc.h"
#include "../error.h"



void init_pin()
{
        DDRA = 0x03;
        DDRB = 0x17;
        DDRC = 0x00;
        DDRD = 0x30;
        PORTA = 0x00;
        PORTB = 0x00;
        PORTC = 0x00;
        PORTD = 0x0C;
}




/* Liest die eingestellte Adresse über das Shiftgegister ein
 *
 * ACHTUNG: die Funktion überschreibt die Ausgänge mit 0 nur während
 *          Initialisierung benutzen!
 */
uint8_t adr_read()
{
        uint8_t adr = 0;

        PIN_SET(R);
        PIN_CLR(DO);
        PIN_CLR(C1);

        PIN_CLR(C2);
        PIN_SET(C1);
        PIN_CLR(C1);
        PIN_SET(C2);

        for (int8_t i = 7; i >= 0; i--) {
                if (PIN_IS_HIGH(DI)) adr |= (1 << i);
                PIN_SET(C1);
                PIN_CLR(C1);
        }

        PIN_CLR(R);

        return adr;
}




/* Hardwareüberwachung Schwellwerte
 */
#define BATTERIE_WARN 580 // ca. 2,9V
#define BATTERIE_ERROR 400 // ca. 2V

#define TEMPERATURE_WARN  790
#define TEMPERATURE_ERROR 820

extern bool output_lock;

/* Überwacht den Batteriestatus und die Temperatur der Ausgänge.
 * Es wird jeweils ein Fehler beim übergang der Warn- bzw. Fehlerschwelle
 * angezeigt. Bei Übertemperatur werden die Ausgänge abgeschaltet und erst
 * wider frei gegeben wenn die Warnschwelle unterschritten wurde.
 */
void hardware_monitor()
{
        static enum {
                temperature_high = 1,
                temperature_critical = 2,
                batterie_low = 4,
                batterie_critical = 8
        } health;


        int16_t value;

        value = get_analog_value(7, 3);
        if (value >= 0) {
                if (value > TEMPERATURE_ERROR) {
                        if (!(health & temperature_critical)) {
                                error(ERR_HITEMP);
                        }

                        output_lock = true;
                        PIN_CLR(C2);
                        PIN_CLR(R);
                        PIN_SET(C2);

                        health |= temperature_critical;

                } else if (value > TEMPERATURE_WARN) {
                        if (!(health & temperature_high)) {
                                error(ERR_HITEMP);
                        }
                        health |= temperature_high;

                } else if (value < TEMPERATURE_WARN - 20) {
                        health &= ~(temperature_high | temperature_critical);
                        PIN_SET(R);
                        output_lock = false;
                }
        }

        value = get_analog_value(6, 3);
        if (value >= 0) {
                if (value < BATTERIE_ERROR) {
                        if (!(health & batterie_critical)) {
                                error(ERR_LOWBAT);
                        }
                        health |= batterie_critical;
                } else if (value < BATTERIE_WARN) {
                        if (!(health & batterie_low)) {
                                error(ERR_LOWBAT);
                        }
                        health |= batterie_low;
                } else if (value > BATTERIE_WARN + 5) {
                        health &= ~(batterie_low | batterie_critical);
                }
        }
}

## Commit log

2012-07-15 Schematic und Layout erstellt
    [ms1616.brd, ms1616.sch]
2012-07-15 74594 durch 74HC594 ersetzt
    [ms1616.brd, ms1616.sch]
2012-07-15 Leichte korrekturen an Schematik und Layout
    [ms1616.brd, ms1616.sch]
2012-07-17 Echtzeituhr eingebaut
    [ms1616.brd, ms1616.sch]
2012-07-17 Werte korrigiert
    [ms1616.brd, ms1616.sch]
2012-07-19 Achtfach-Ausgangsmodul erstellt
    [out8.brd, out8.sch]
2012-07-19 LEDs auf Ausgangsplatine hinzugefügt
    [out8.brd, out8.sch]
2012-07-22 Multimaster mit 16 Eingängen erstellt
    [mm16.brd, mm16.sch, ms1616.brd]
2012-07-22 Busstecker auf Ausgangsboard ersetzt; kleinere Layoutanpassungen
    [out8.brd, out8.sch]
2012-07-22 Batterie auf Multimaster hinzugefügt
    [mm16.brd, mm16.sch]
2012-07-24 Dipschalter durch Drehschalter ersetzt; 74HC594 durch 74HC595 ersetzt; Signalleitungen gedreht.
    [mm16.brd, mm16.sch, out8.brd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]
2012-07-26 Leiterbahn verschoben
    [mm16.brd]
2012-07-26 Anschlüsse neu possitioniert und Bohrungen hinzugefügt
    [mm16.brd, mm16.sch]
2012-07-26 Alarme angeschlossen; Detailverbesserungen am Layout
    [mm16.brd, mm16.sch]
2012-07-26 Werte im Schema und Bohrungen im Layout hinzugefügt
    [mm16.brd, mm16.sch, out8.brd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]
2012-07-28 Anschlussklemmen ausgetauscht
    [mm16.brd, mm16.sch, out8.brd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]
2012-07-28 Optionaler Abschlusswiderstand eingefügt
    [mm16.brd, mm16.sch, out8.brd]
2012-07-28 Batteriehalter ausgetauscht
    [mm16.brd, mm16.sch]
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2012-07-29 BUGFIX: i2c Slaveadressierung falsch
    [i2c.c]
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2012-07-31 BUGFIX: Eingänge werden nicht gelesen; Ausgänge nicht geschrieben.
    [main.c]
2012-07-31 Pinabstand vom Bateriehalter korrigiert
    [mm16.brd, mm16.sch]
2012-08-05 rtc_time2str implementiert; BUGFIX: bcs wird nicht gesendet und eb1 wird nicht eingelesen
    [i2c.c, main.c]
2012-08-05 BUGFIX: Nur jede zweite Nachricht wurde empfangen
    [main.c]
2012-08-06 Boards beschriftet
    [mm16.brd, mm16.sch, out8.brd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]
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2012-08-13 Mergeleiche entfernt; Defaultlayer aktiviert
    [out8.brd]
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2012-09-05 BUGFIX: UN, ON und = funktionieren nicht richtig
2012-09-11 dc_adapter erstellt
    [dc_adapter.brd, dc_adapter.sch]
2012-09-12 Debugfunktion erweitert; BUGFIX: Progarammablauf fehlerhaft bei S, R und X
2012-09-18 Sicherheit und LED für Spannungsversorgung hinzugefuegt
    [mm16.brd, mm16.sch]
2012-11-27 BUGFIX: Bei Serienschaltern reagieren manchmal beide Eingänge
    Das Problem kommt vermutlich von einer kapazitiven überlagerung auf der
    Schaltleitung. Das Eingangssignal muss jetzt länger anstehen bevor
    darauf reagiert wird. Das löst hoffentlich das Problem.
    [main.c]
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2013-04-22 Erste vorläufige Implementation
    [dig_ac230.brd, dig_ac230.sch]
2013-04-22 Bauteile neu positoniert
    [dig_ac230.brd, dig_ac230.sch]
2013-04-22 rev1 geroutet
    [dig_ac230.brd, dig_ac230.sch]
2013-04-22 kleinere Designfehler beseitigt
    [dig_ac230.brd]
2013-04-22 Leiterbahnführung verbessert; Analog ground verbessert
    [dig_ac230.brd]
2013-04-22 Statusleds, Temperatur- und Batteriemessung hinzugefügt
    [dig_ac230.brd, dig_ac230.sch]
2013-04-22 Halbleiterrelais wegen gehäuse versetzt
    [dig_ac230.brd, dig_ac230.sch]
2013-04-22 Schematik übersichtlicher gemacht; Bauteile neu benannt; Werte ergänzt
    [dig_ac230.brd, dig_ac230.sch]
2013-04-22 Bauteile wegen Beschriftung ausgetauscht
    [dig_ac230.brd, dig_ac230.sch]
2013-04-22 Beschriftung angepasst
    [dig_ac230.brd]
2013-04-22 Fehlende Leiterbahn erzeugt; keine Stopmaske bei Vias
    [dig_ac230.brd]
2013-04-22 Batteriespannungsdioden versetzt
    [dig_ac230.brd]
2013-04-22 Netzklasse netz erstellt und zugeordnet
    [dig_ac230.brd, dig_ac230.sch]
2013-04-22 Eingänge auf ltv-354t umgestellt
    [dig_ac230.brd, dig_ac230.sch]
2013-04-22 Bezeichnungen angepasst; Position auf Board angepasst
    [dig_ac230.brd, dig_ac230.sch]
2013-05-06 Wert von D101 geändert
    [dig_ac230.brd, dig_ac230.sch]
2013-05-06 Anschlüsse versetzt
    Anschlüsse sind jetzt nicht mehr korrekt unter den Löchern dafür
    müsste die Platine aber ins Gehäuse passen
    [dig_ac230.brd]
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2013-08-15 Verzeichnisstruktur geändert
    [dc_adapter.brd, dc_adapter.sch, dig_ac230.brd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]
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2013-10-03 Tippfehler in Firmware behoben
    [main.c]
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2013-10-03 BUGFIX: Datenfehler nach stop und run
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2014-01-27 BUGFIX: Unbekannter Befehl bei zu vielen Interrupts
2014-01-27 BUGFIX: Bits der ungeraden Bytes werden nicht verarbeitet
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2014-02-05 BUGFIX: Shared library wird nicht richtig erstellt
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2014-02-27 BUGFIX: Endlosreset auf atmega1284
    [main.c]
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2014-03-08 BUGFIX: Beim Prototype wird noch die Adresse verdoppelt
2014-03-08 BUGFIX: Falsche ADC Werte wenn der wert gegen Null tendiert
2014-03-08 BUGFIX: Keine Hysterese bei Temperatur- und Batteriewarnung; Temperaturwerteabschaltwerte angepasst.
    [main.c]
2014-09-28 Revision 2 von dig_ac230 wird zur USB variante
    [dig_usb.brd, dig_usb.sch]
2014-09-28 dig_usb auf AT90USB1287 umgestellt
    [dig_usb.brd, dig_usb.sch]
2014-10-05 IO Bereich der unteren Platine geroutet
    [dig_usb.brd, dig_usb.sch]
2014-10-05 Einiges auf dig_usb controllerboard gerouted
    [dig_usb.brd, dig_usb.sch]
2014-10-08 USB Stecker und Quarz hinzugefügt
    [dig_usb.brd, dig_usb.sch]
2014-10-08 dig_usb vorläufig komplett geroutet
    [dig_usb.brd, dig_usb.sch]
2014-10-09 Padgröße bei Wannenstecker für dig_usb angepasst
    [dig_usb.brd, dig_usb.sch]
2014-10-09 Widerstandsarrays für LEDs gegen CHIP0805 bei dig_usb getauscht
    [dig_usb.brd, dig_usb.sch]
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2014-10-11 Unterer Wannenstecker auf dig_usb verschoben um Platz für Wärmebrücke zu machen
    [dig_usb.brd, dig_usb.sch]
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2014-10-22 UVCC und HWB angeschlossen
    [dig_usb.brd, dig_usb.sch]
2014-10-22 Steckbare Anschlüsse zu dig_usb hinzugefügt
    [dig_usb.brd, dig_usb.sch]
2014-10-22 RJ45 Buchsen für Bus an dig_usb
    [dig_usb.brd, dig_usb.sch]
2014-10-23 Routing auf dig_usb verfeinert
    [dig_usb.brd, dig_usb.sch]
2014-10-26 dig_usb: Bauteile neu nummeriert und Plan etwas verschönert
    [dig_usb.brd, dig_usb.sch]
2014-10-26 dig_usb: Beschriftung besser angeordnet
    [dig_usb.brd, dig_usb.sch]
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2014-11-10 Alternativer DC/DC Wandler und Ausgangsfilter hinzugefügt
    [dig_usb.brd, dig_usb.sch]
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2014-11-17 Zusätzlicher Kondensator für UVcc; HWB mit INT4 verbunden
    [dig_usb.brd, dig_usb.sch]
2014-11-17 I2C EEPROM hinzugefügt auf dig_usb hinzugefügt
    [dig_usb.brd, dig_usb.sch]
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2014-12-30 BUGFIX: DDR für rote LED auf CPU USB falsch
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2015-07-22 BUGFIX: Doppelinitialisierung des Programms bei wechsel von RUN auf DEBUG
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2015-09-11 BUGFIX: AM wird nicht in CPUs ohne Programm übertragen
2015-09-29 BUGFIX: Reihenfolge der Ein- und Ausgänge bei CPU_USB vertauscht
2015-12-22 BUGFIX: Bitreihenfolge der IOs bei USB_CPU vertauscht
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2016-06-01 Erster entwurf des Klingelmoduls
    [dm_out.brd, dm_out.sch]
2016-08-17 Minimale Layoutverbesserung im Türmodul
    [dm_in.brd]
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2017-01-18 BUGFIX: Homelogic startet ständig neu
    [main.c]
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2017-01-19 BUGFIX: Timer reagieren nicht mit compiler update
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

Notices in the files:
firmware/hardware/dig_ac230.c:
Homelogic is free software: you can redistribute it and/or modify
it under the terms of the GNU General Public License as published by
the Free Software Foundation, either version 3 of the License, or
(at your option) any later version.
